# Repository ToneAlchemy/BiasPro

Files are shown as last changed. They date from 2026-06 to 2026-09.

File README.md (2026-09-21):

# 🎛️ Arduino Tube Amp BiasPro

This repository contains the complete, mathematically hardened firmware for a professional-grade, dual-probe vacuum tube BiasPro. Designed for guitar amplifier technicians, this tool provides real-time, high-resolution measurements of Plate Voltage, Cathode Current, and True Plate Dissipation (Watts & %) for power tubes (e.g., 6L6GC, EL34, 6V6, KT88).

This firmware was completely re-architected from scratch using modern, memory-safe embedded C++ principles to eliminate dynamic memory leaks and ensure rock-solid physical safety lockouts.

> **Current firmware version: v1.1.1** — see [CHANGE_LOG.md](CHANGE_LOG.md) for the full change history. Highlights since v1.0.0: a **vertically stacked, horizontally centered layout on the Tube Select and Profile Manager screens** (with improved line spacing for clear reading), a **Hold LEFT shortcut** to escape the Profile Manager directly to Tube Select, a **live plate-voltage readout on the Calibration screen** (match it to your DMM as you adjust), **sensor-glitch rejection** so a noisy ADC read can't false-release the lockout or flash 0 V, **profile-store protection** so a bad edit can't wipe your saved tube profiles, and a **flicker-free VOLTAGE LOCKOUT screen**.

| **1. Splash Screen** | **2. Tube Select** | **3. Live Bias Mode** |
| :---: | :---: | :---: |
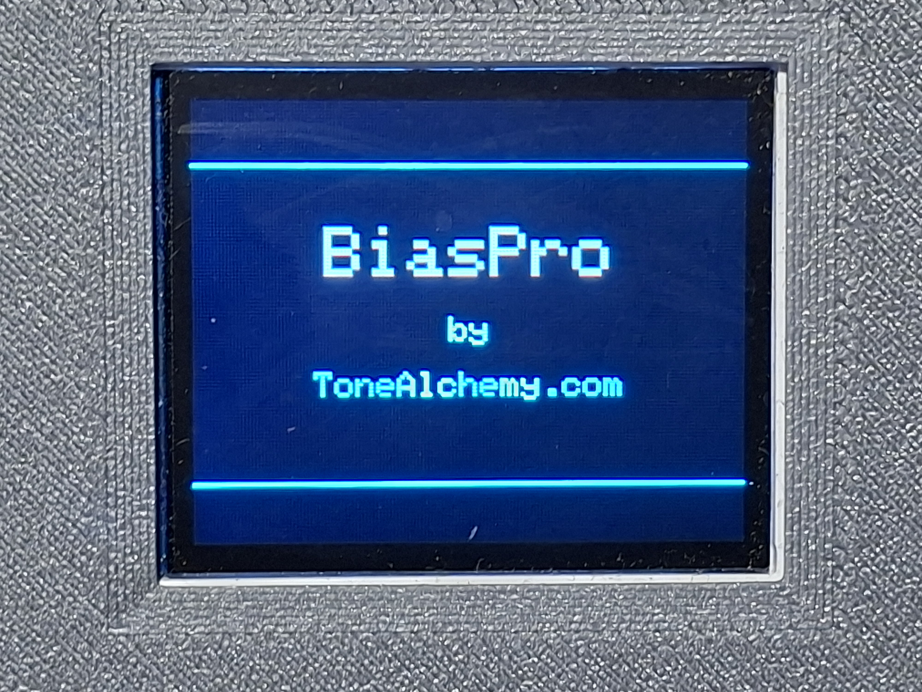
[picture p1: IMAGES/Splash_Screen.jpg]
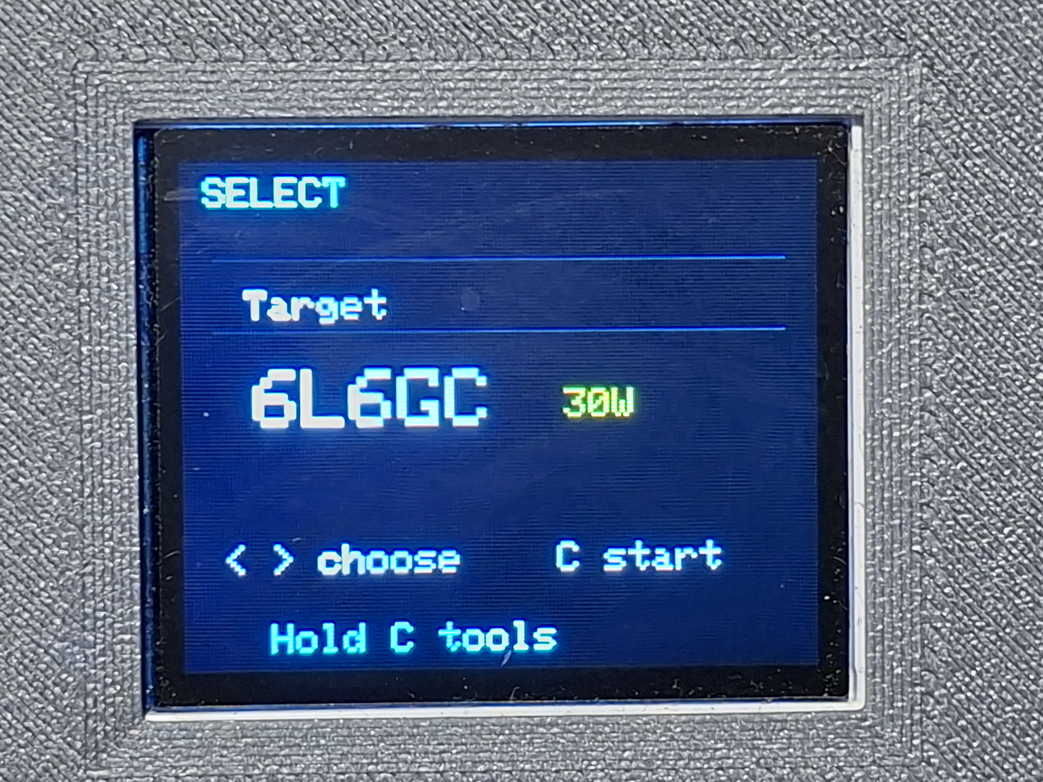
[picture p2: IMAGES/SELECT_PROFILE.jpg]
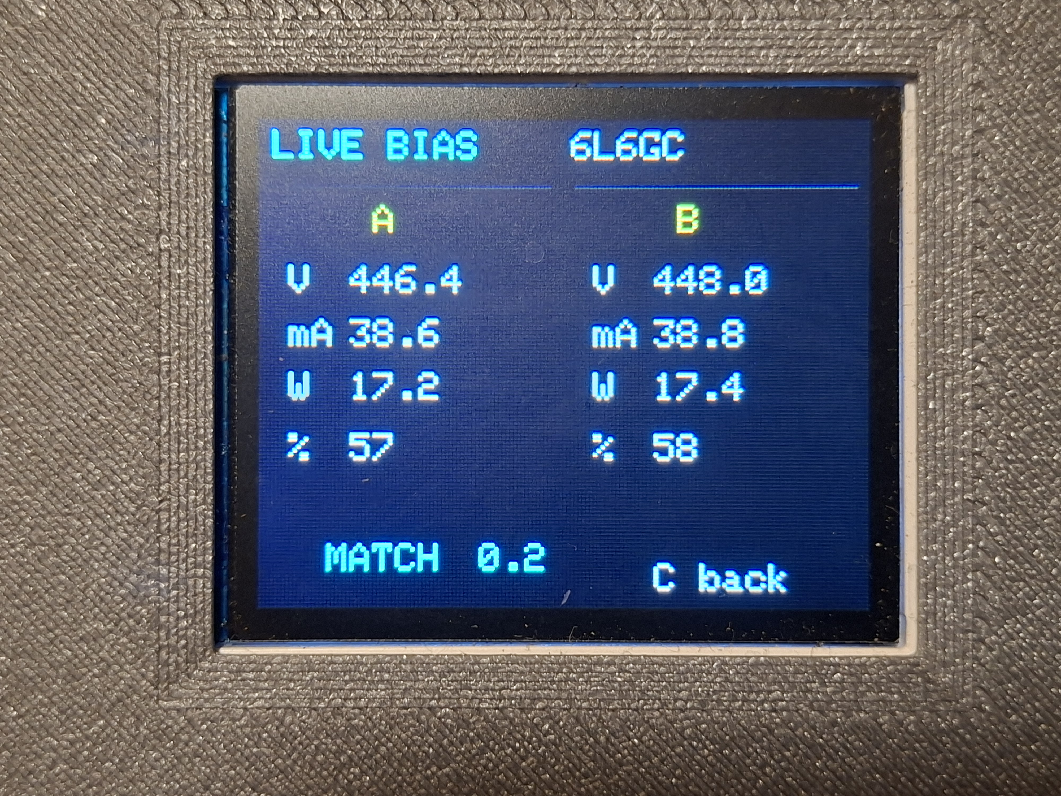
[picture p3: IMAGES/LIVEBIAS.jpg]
|  |  |  |
| **4.  Calibration** | **5. Profiles Manager** | **6. Profile Edit** |
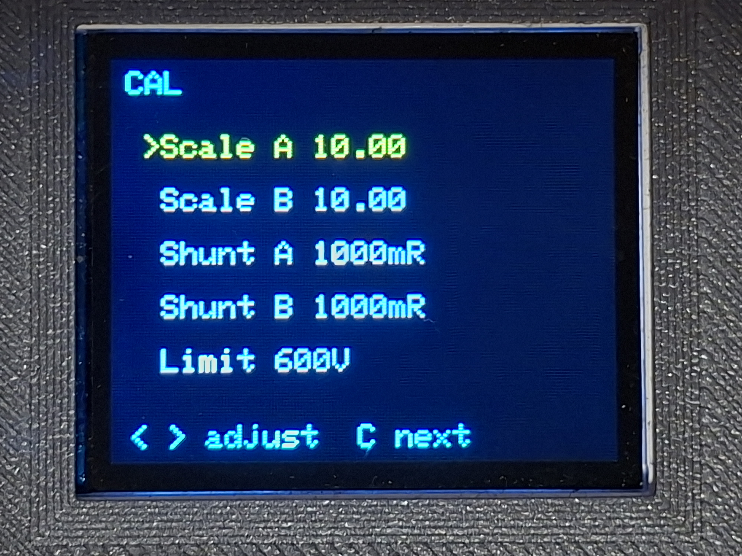
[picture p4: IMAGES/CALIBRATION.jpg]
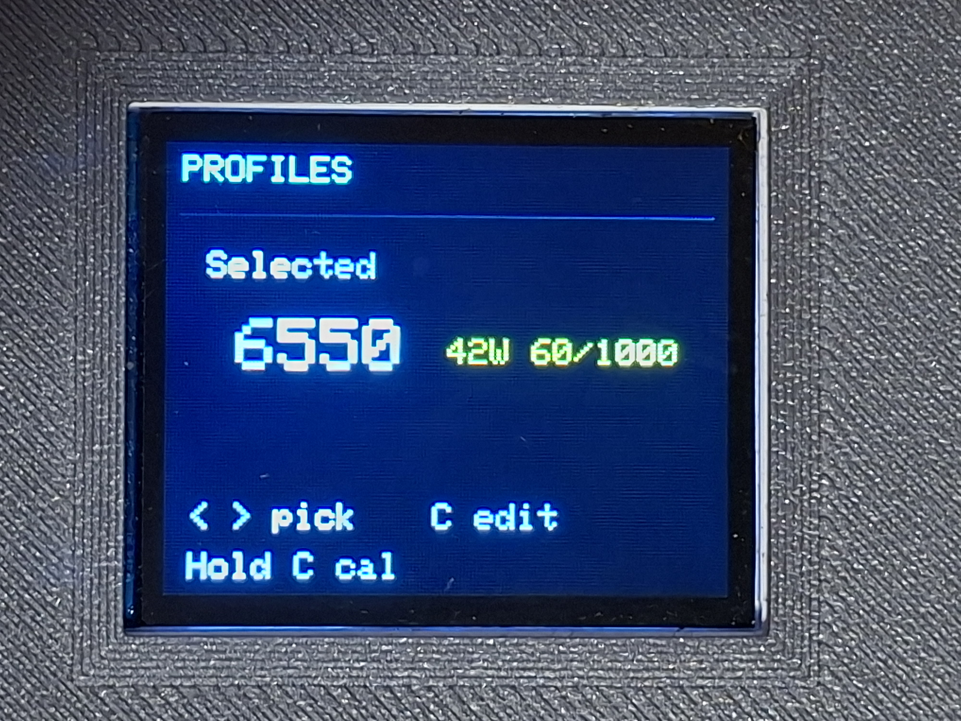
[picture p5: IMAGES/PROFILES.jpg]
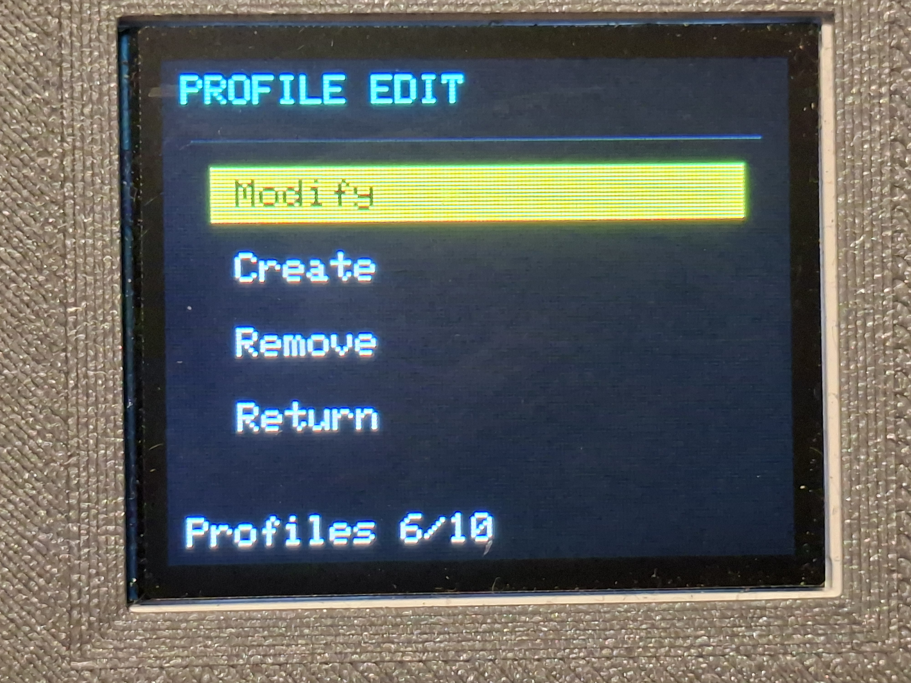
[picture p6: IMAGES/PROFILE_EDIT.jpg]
|  |  |  |
| **7. EDIT PROFILE** | **8. BiasPro Enclosure** | **9. BiasPro - Setup** |
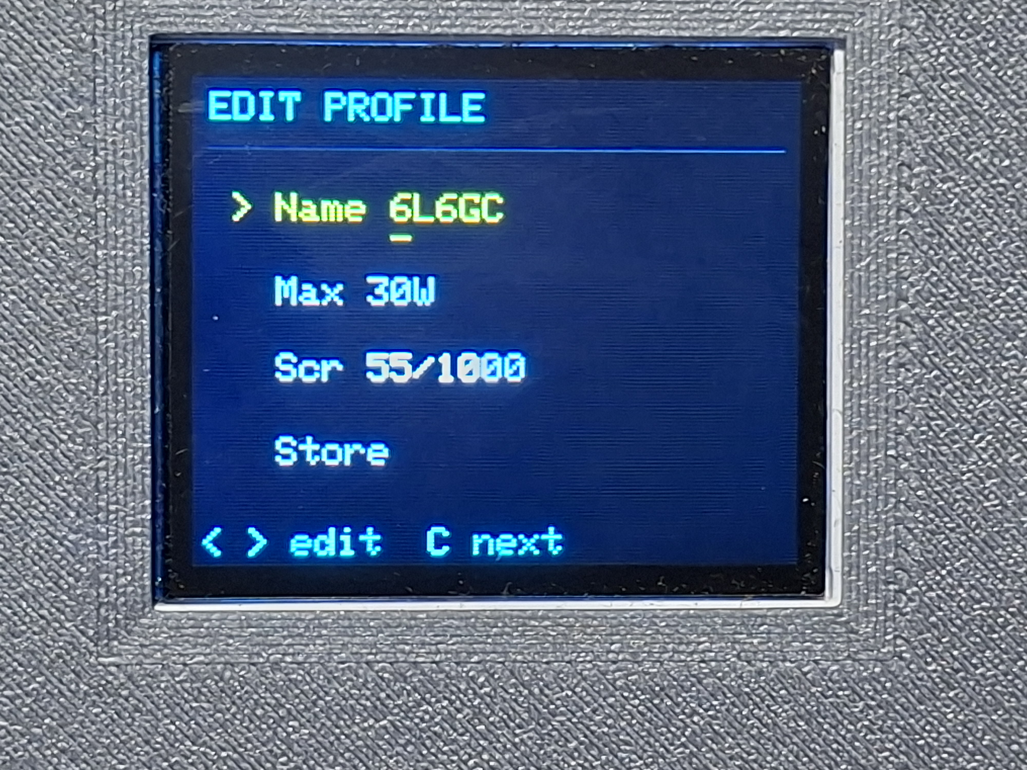
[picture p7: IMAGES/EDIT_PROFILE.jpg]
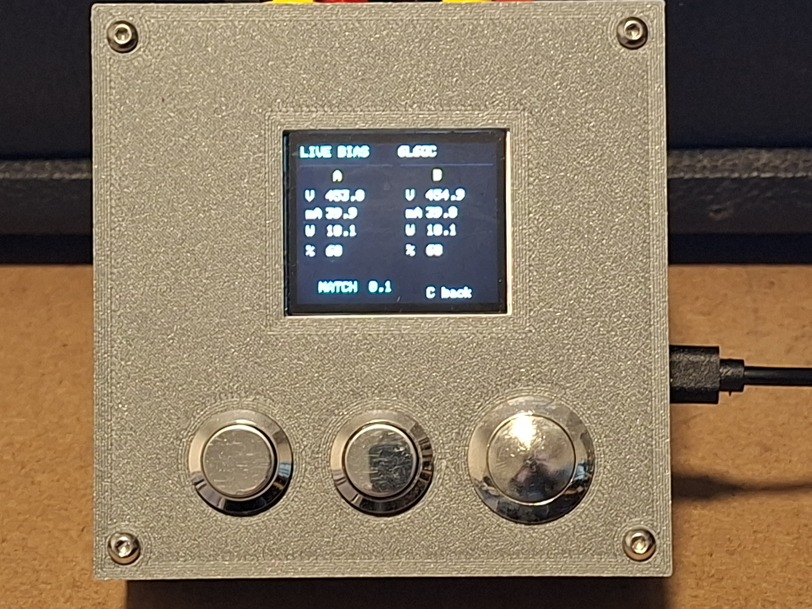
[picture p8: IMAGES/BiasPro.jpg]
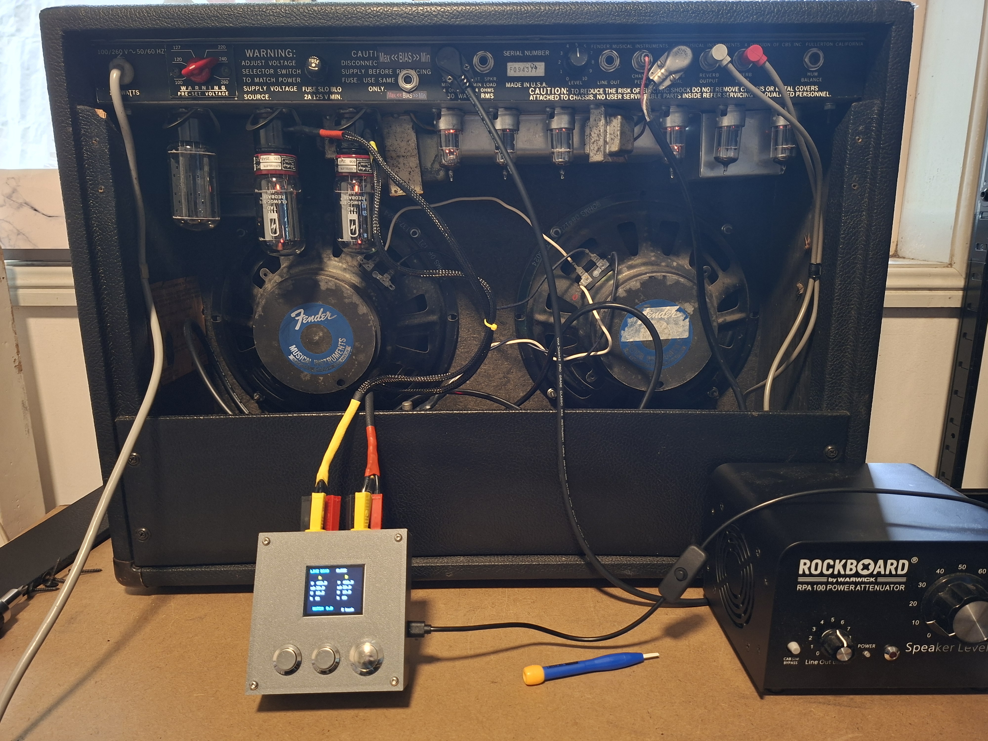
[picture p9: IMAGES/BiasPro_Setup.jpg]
|  |  |  |

---

## ⚠️ High-Voltage Safety Warning
**LETHAL VOLTAGES ARE PRESENT IN TUBE AMPLIFIERS.**

Tube amplifiers store lethal voltages in their filter capacitors even after being unplugged. This firmware is only a measurement tool; it **cannot** make unsafe wiring or handling safe. 
* Never connect the USB port to a computer while the probes are plugged into a live amplifier. 
* Always use a dummy load or speaker cabinet.
* If you are not trained in high-voltage safety, take your amplifier to a qualified technician. Build and use this project entirely at your own risk.

---

> [!CAUTION]
> ## ⚠️ WARNING: HIGH VOLTAGE SAFETY
>
> **Tube amplifiers contain lethal high voltage (often 400V–500V+), even when powered off and unplugged.**
>
> This project involves building and using test equipment that interfaces directly with these dangerous circuits.
> * **Risk of Death:** Incorrect wiring of the bias probes or misuse of this device can expose you to lethal current.
> * **Filter Capacitors:** High voltage can remain stored in the amplifier's capacitors long after the power is cut. You must know how to safely drain filter capacitors before opening any chassis.
> * **Qualified Personnel Only:** If you are not trained in high-voltage safety or are uncomfortable working with live circuits, **do not build or use this device**. Take your amplifier to a qualified technician instead.
>
> **DISCLAIMER & NO SUPPORT:** This project is provided "as is" with **no warranty and no technical support**. The author cannot provide assistance with assembly, troubleshooting, or code modifications. The author assumes no liability for injury, death, or equipment damage resulting from the use or construction of this device. **Use entirely at your own risk.**

> [!IMPORTANT]
> ### ⚡ Critical Safety: Capacitor Discharge
> Before touching any internal component or connecting probes to a chassis, you must verify the filter capacitors are drained.
>
> * **The Golden Rule:** Always measure with a multimeter to confirm 0VDC before touching anything.
> * **Discharge Tool:** Do not rely on the amp to drain itself. Use a dedicated **Capacitor Discharge Tool** to safely bleed off voltage.
>      * *DIY Tip:* You can build one using a high-wattage resistor (e.g., **2kΩ to 5kΩ, 5 Watts**) wired to a probe and an alligator clip for ground. This slows the discharge **and** prevents sparking, unlike a screwdriver short.
> * **One-Hand Rule:** When working on live amps, keep one hand in your pocket to prevent current from passing across your chest/heart.

> [!NOTE]
> ### 🛡️ Recommended Safety Gear
> If you are working inside a live amplifier chassis, we strongly recommend using the following safety equipment:
> 
> * **Isolation Transformer:** This isolates the amplifier from the mains earth ground, significantly reducing the risk of lethal shock if you accidentally touch a live component while grounded.
> * **Dim Bulb Limiter (Current Limiter):** Essential when powering up an amplifier for the first time after a repair. It prevents catastrophic damage (blown transformers) if there is a short circuit.
>      * **⚠️ CRITICAL WARNING:** Do **NOT** attempt to set the final bias while running through a Dim Bulb Limiter. The limiter drops the wall voltage, which lowers the plate voltage and gives false low bias readings. Always bypass the limiter for the final precision bias adjustment.
> * **Variac (Variable Transformer):** Highly recommended for two purposes:
>      1.  **Voltage Stabilization:** Wall voltage fluctuates. A Variac allows you to set the input voltage exactly to your country's standard (e.g., 240V in Australia, 120V in USA, 230V in UK). This ensures your bias readings are accurate and consistent, rather than drifting with high/low wall voltage.
>      2.  **Soft Start / Reforming:** Useful for slowly bringing up the voltage on vintage amplifiers to reform old capacitors safely.

> [!TIP]
> **New to Biasing?** Check out our dedicated guide:
> ### 📖 [Read the Step-by-Step Biasing Guide](BIASING_GUIDE.md)
> *Learn how to safely bias Fender Prosonic & Fixed-Bias Amps.*

---

## ⚙️ Hardware Specifications

* **MCU:** Arduino Nano / ATmega328P
* **Display:** 1.8" 128×160 ST7735/ST7735S SPI TFT (Adafruit PID 358 or compatible generic clone; see [Display Selection & Compatibility Guide](#18-tft-display-selection--compatibility-guide) below)
* **ADC:** ADS1115 (16-bit) at I2C address `0x48`
* **Inputs:** Three tactile switches (Left, Right, Center)

### Immutable Pin Map
| Function | Arduino Nano Pin |
| :--- | :--- |
| **TFT SCLK/SCL** | D13 |
| **TFT MOSI/SDA** | D11 |
| **TFT CS** | D10 |
| **TFT DC** | D9 |
| **TFT RST** | D8 |
| **Button Center** | D7 (Uses `INPUT_PULLUP`) |
| **Button Right** | D6 (Uses `INPUT_PULLUP`) |
| **Button Left** | D5 (Uses `INPUT_PULLUP`) |
| **ADS1115 SDA** | A4 |
| **ADS1115 SCL** | A5 |

### 🖥️ 1.8" TFT Display Selection & Compatibility Guide

When sourcing displays for BiasPro, you will encounter two primary hardware paths: the official Adafruit breakout or generic clone modules. Understanding their electrical architecture is essential for proper wiring and long display life:

| Feature | Adafruit 1.8" TFT Breakout (PID 358) | Generic Clone Module (`Driver IC: ST7735S` / `NOMEN_TEC`) |
| :--- | :--- | :--- |
| **Driver IC** | **ST7735R** | Usually **ST7735S** |
| **Onboard 3.3V LDO Regulator** | ✅ Yes (ultra-low-dropout 3.3V regulator) | ⚠️ **Usually present (`662K`), but verify `U1` & `J1`** |
| **Onboard Logic Level Shifter** | ✅ Yes (active CD74HC4050 buffer IC) | ❌ **None** (pins route straight to glass ribbon) |
| **5V Supply Compatibility** | ✅ Yes (accepts 3.3V – 5V on `VCC`) | ✅ Yes (if `U1` is populated and `J1` is open) |
| **5V Logic Compatibility** | ✅ Native 5V plug-and-play | ⚠️ **Requires 1kΩ to 1.5kΩ series resistors on SPI/control lines** |
| **Header Pin Labels** | `LITE, MISO, SCK, MOSI, TFT_CS, CARD_CS, D/C, RESET, VCC, Gnd` | `GND, VCC/VDD, SCL, SDA, RES/RST, DC, CS, BL/BLK` |

> [!NOTE]
> **Important Distinction on Adafruit PID 358 vs. PID 618:**  
> The official recommended reference part is the **Adafruit PID 358** assembled breakout (which includes the mounting PCB, microSD slot, 3.3V regulator, and CD74HC4050 level shifter).  
> In contrast, **Adafruit PID 618 is the raw, unmounted 1.8" TFT panel only** (flexible ribbon cable, no PCB). PID 618 is strictly 3.3V-only and requires external regulation and level shifting when paired with a 5V Arduino Nano.

---

#### Board Routing & Configuration Details

The `BiasPro_InputProtection_v3` PCB routes the global **5V** rail directly to Pin 8 (`VCC`) of the display header, and routes digital pins `D8`, `D9`, `D10`, `D11`, and `D13` straight to the display's SPI control lines without inline resistor pads. Review the configuration requirements for your specific display:

##### 1. Official Adafruit Breakout (PID 358) — *Recommended Reference Part*

The reference hardware design targets the **Adafruit PID 358** assembled breakout natively:

* **Power:** Connect `VCC` to Arduino Nano 5V (or 3.3V; the onboard regulator safely handles 3.3V–5V input) and `GND` to Arduino GND.
* **Signals:** Wire directly to the Arduino Nano with **no external resistors required** (the onboard CD74HC4050 buffer translates 5V logic down to 3.3V safely):
  * Nano `D13` → Adafruit `SCK`
  * Nano `D11` → Adafruit `MOSI`
  * Nano `D10` → Adafruit `TFT_CS`
  * Nano `D9`  → Adafruit `D/C`
  * Nano `D8`  → Adafruit `RESET`
* **Backlight:** Connect `LITE` to 3V3 or 5V (or to an Arduino PWM pin if software brightness control is desired).
* **Unused Pins:** `CARD_CS` and `MISO` belong to the onboard microSD card socket and remain unconnected in BiasPro.
* **Firmware Support:** BiasPro’s firmware uses `tft.initR(INITR_18BLACKTAB)` via the `Adafruit_ST7735` library, targeting the PID 358 natively.

---

##### 2. Generic / Chinese Clone Modules (ST7735S)

Budget 8-pin breakout modules (frequently marked *Driver IC: ST7735S* or *NOMEN_TEC V2.0*) run on native 3.3V silicon and lack active logic-level translation buffers.

* **VCC Power Compatibility (`U1` & `J1` Check):**
  * Inspect the rear PCB of the module: most clones include a 3-pin 3.3V LDO regulator marked **`662K`** (or `AMS1117-3.3`) at footprint **`U1`**, alongside an unbridged solder jumper **`J1`**.
  * If `U1` is populated and `J1` is open, feeding 5V into `VCC` is completely safe (the regulator steps 5V down to 3.3V for internal panel power).
  * **Warning:** If `U1` is unpopulated and `J1` is bridged, the module is strictly 3.3V-only. Connecting 5V to `VCC` will destroy the panel.
* **5V Logic Levels & Clamping:**
  * Because generic modules omit active buffer ICs, driving them directly with the Nano's 5V SPI lines forces the ST7735's internal silicon clamping diodes to shunt the excess voltage down to 3.3V.
  * **Intermittent Bench Biasing (Stock Direct Connection):** For standard tube biasing workflows (5 to 15 minutes of bench runtime per amplifier), the direct connection operates reliably without immediate failure.
* **Extended / Continuous Duty Cycles (Recommended Protection):** For long-term reliability and day-long bench operation, insert **1kΩ to 1.5kΩ series resistors** into every digital control line to eliminate clamping stress and keep the display controller cool:
  * Nano `D13` → [1kΩ Resistor] → Display `SCL` / `SCK`
  * Nano `D11` → [1kΩ Resistor] → Display `SDA` / `MOSI`
  * Nano `D10` → [1kΩ Resistor] → Display `CS`
  * Nano `D9`  → [1kΩ Resistor] → Display `DC` / `A0`
  * Nano `D8`  → [1kΩ Resistor] → Display `RES` / `RESET`
* **PCB Assembly Note:** Because the `BiasPro_InputProtection_v3` PCB routes the Nano directly to the display header without inline resistor pads, builders opting for series resistors should wire the clone module off-board or install inline resistors along the wiring harness rather than soldering the display directly flush into the PCB header.
* **Backlight (`BL` / `BLK`):** The onboard transistor (`Q1` / `J3Y`) and base resistor handle switching. Connect `BL` to the Nano's `3V3` pin, or to an Arduino GPIO pin through a 1kΩ resistor if software dimming is desired.

---

## 🛠️ Build & Flash Instructions

### 1. Pinned Dependencies
To guarantee a successful compile, you **must** use these exact library versions in the Arduino IDE:
* `Adafruit GFX Library` v1.12.5
* `Adafruit ST7735 and ST7789 Library` v1.11.0
* `Adafruit BusIO` v1.17.4

### 2. CRITICAL: 99% Flash Memory Limit & Bootloaders
The firmware compiles to approximately **30,626 bytes** of program storage. This is a very tight fit on older hardware, but it will successfully flash to both new and old Arduino Nanos.

* **Newer Arduino Nano (Standard Bootloader):** If you have a newer official Nano or a high-quality modern clone, use the `Processor: ATmega328P` setting in the Arduino IDE. These boards use the modern *Optiboot* bootloader, which leaves 32,256 bytes of usable flash space. The firmware will fit easily with roughly **1.6KB to spare**.

* **Older Arduino Nano & Generic Clones (Old Bootloader):** Many cheaper clones and older Nanos use the legacy bootloader, which takes up more space and leaves exactly 30,720 bytes of usable flash space. The firmware **will still successfully flash** using the `Processor: ATmega328P (Old Bootloader)` setting, fitting with roughly **94 bytes to spare**:
  ```text
  Sketch uses 30626 bytes (99%) of program storage space. Maximum is 30720 bytes.
  Global variables use 750 bytes (36%) of dynamic memory, leaving 1298 bytes for local variables. Maximum is 2048 bytes.
  ```
  It works perfectly, but you have very little room to add additional features or text without overflowing the memory.

* **Need more space on an old Nano?** You can manually upgrade an old Nano to the modern *Optiboot* bootloader using an ISP programmer. Once upgraded, you simply change your board selection in the Arduino IDE to **"Arduino Uno"** to unlock the extra 1.5KB of flash space.

### 3. EMI & I2C Freeze Protection
Tube amplifiers are electrically noisy environments. High voltage spikes, flyback EMF, or loose tube socket connections can create strong Electromagnetic Interference (EMI) that can lock up the internal I2C bus connecting the Arduino to the ADS1115 ADC.

To protect against these EMP-like events, this firmware completely bypasses the standard Adafruit ADC library and manually writes to the I2C registers. More importantly, it utilizes the modern `Wire.setWireTimeout(25000, true)` feature. 

* **How it works:** If the I2C bus freezes due to interference, the system detects the hang within 25 milliseconds, automatically resets the I2C hardware pins, and immediately resumes reading the Bias probes without ever rebooting the Arduino or losing your place on the screen.

* **Why no Hardware Watchdog Timer (WDT)?** Older versions of this project used the hardware WDT. However, a severe silicon bug in common LGT8F328P Arduino Nano clones caused the WDT to trigger infinite boot-loop crashes during UI updates. The software-level `Wire` timeout is infinitely more reliable, handles EMI elegantly, and completely avoids these bootloader bugs.

#### Hardware I²C Pull-Up Reinforcement (EMI Hardening)
In addition to the software timeout recovery, the physical BiasPro hardware reinforces the ADS1115 I²C bus with auxiliary pull-up resistors:
* **`SDA` $\rightarrow$ 4.7kΩ $\rightarrow$ `VDD`**
* **`SCL` $\rightarrow$ 4.7kΩ $\rightarrow$ `VDD`**

These $4.7\text{ k}\Omega$ metal-film resistors were added during live amplifier testing to strengthen the I²C bus against EMI-induced corruption and bus lockups in electrically aggressive valve-amplifier environments. By lowering the bus impedance and sharpening the $SDA$/$SCL$ rising edges, the bus becomes significantly more immune to capacitively coupled noise from high-voltage plate leads and transformer fields.

Many common ADS1115 breakout modules already include $10\text{ k}\Omega$ onboard pull-up resistors. Adding external $4.7\text{ k}\Omega$ resistors places them in parallel, resulting in an effective bus pull-up impedance of approximately $\approx 3.2\text{ k}\Omega$ (drawing only $\approx 1.56\text{ mA}$ sink current at 5V, comfortably within the $3\text{ mA}$ I²C standard limit). These hardware pull-ups work synergistically with the firmware’s `Wire.setWireTimeout` mechanism to deliver rock-solid stability.

---

## ⚠️ Troubleshooting

### 1. Upload Failed? (stk500 Error)
If you are unable to upload the firmware and see an error like `stk500_recv(): programmer is not responding`:

* **The Cause:** You are likely using an older Arduino Nano (or a generic clone) that uses the legacy bootloader.

* **The Fix:** In the Arduino IDE, go to **Tools > Processor** and change the setting from "ATmega328P" to **"ATmega328P (Old Bootloader)"**. Then try uploading again.
* *Note:* Newer official Nanos (and USB-C versions) usually use the standard "ATmega328P" setting.

### 2. The "Boot Loop" Issue (Legacy Hardware)
Some older Arduino Nano boards (and many low-cost clones) came with an outdated "Bootloader" that had a bug preventing the chip from recovering correctly after a hardware Watchdog Reset. 

* **The Fix:** This has been permanently fixed in this modern codebase! We completely stripped out the hardware Watchdog Timer and replaced it with a targeted `Wire.setWireTimeout` bus reset. You should no longer experience infinite boot loops when encountering EMI. If you do, ensure you have correctly installed the `Wire` library updates in the Arduino IDE.

### 3. Adafruit Display Clones ST7735 1.8" TFT - White Screen / Static / Wrong Colors?
If your display lights up but shows static, garbage pixels, or wrong colors:

* **The Cause:** You likely have a "Green Tab" or "Red Tab" clone display. The plastic tab on the screen protector often indicates the internal driver version.

* **The Fix:** Open the firmware source code (`DisplayManager.cpp` or main `.ino` configuration) and find the initialization line: `tft.initR(INITR_18BLACKTAB);` 
Change it to one of the following and re-upload until the screen looks correct:
  * `tft.initR(INITR_18GREENTAB);`
  * `tft.initR(INITR_18REDTAB);`

### 4. Arduino Nano "L" LED Flickering Constantly?
If you notice the onboard yellow/orange **`L`** LED on your Arduino Nano flickering continuously while the device is running:

* **This is completely normal and indicates healthy operation.**
* On the Arduino Nano hardware, the onboard `L` LED is hardwired directly to digital pin **`D13`**.
* In BiasPro, `D13` serves as the high-speed SPI Clock (`TftSclkPin`). Every time the live bias values update (multiple times per second), thousands of SPI clock pulses toggle D13 at high frequency.
* The flickering `L` LED effectively functions as a live hardware activity monitor showing active SPI communication between the ATmega328P and the display.

---

## 💻 Software & Development Environment

This project is written as a standard Arduino sketch (`.ino`) and was developed using the official **Arduino IDE**.

* **Recommended Method:** We strongly recommend using the **Arduino IDE** for the easiest setup. Its built-in *Library Manager* (Tools > Manage Libraries) makes it simple to install the required dependencies (e.g., Adafruit GFX) without complex manual configuration.

* **Alternative IDEs:** Advanced users can compile this code in other environments, such as **Visual Studio Code (with PlatformIO)** or **Microchip Studio**. However, please note that you will need to manually manage library paths and dependencies.
* **📥 Download Official Arduino IDE:** [Download Official Arduino IDE](https://www.arduino.cc/en/software)

---

## 🧪 Tests

The pure calculation and storage logic (bias math, probe classification, EEPROM
checksums/validation, and the over-voltage protection state machine) lives in
Arduino-independent units (`MathCalculations`, `ProtectionSystem`, `StorageCore`)
so it can be verified on a PC with any C++17 compiler — no board required. The
host tests link the **actual firmware sources**, not a copy, so they cannot drift
from what ships.

```bash
# From the repository root, with g++ (or clang++):
g++ -std=c++17 -I BiasPro test/host_calculation_tests.cpp \
    BiasPro/MathCalculations.cpp BiasPro/ProtectionSystem.cpp \
    BiasPro/StorageCore.cpp -o biaspro_host_tests
./biaspro_host_tests        # expect: "host calculation tests passed"
```

A second, source-level UI regression check (PowerShell) asserts that the display
code keeps using its incremental-redraw pattern and that the safety-screen
routing stays intact:

```powershell
powershell -ExecutionPolicy Bypass -File test/screen_redraw_static_check.ps1
```

---

## Features

BiasPro introduces professional-grade data integrity and safety features not found in standard DIY alternatives.

### 🛠 Core Functionality
* **Dual Probe Measurement:** Simultaneous real-time monitoring of Tube A and Tube B.

* **True Plate Dissipation:** Calculates power (Watts) and dissipation percentage based on the specific tube type.

* **Screen Current Correction:** Implements industry-standard math to subtract estimated screen current, ensuring the displayed bias represents true *Plate* dissipation, not just Cathode current.

### 💾 Robust Data Integrity
* **Checksum Protection:** The EEPROM data includes a computed checksum. If the memory is corrupted or a new chip is installed, the system detects the error and automatically restores safe default values, preventing dangerous behavior.

* **Safety Clamps:** The Calibration Menu now prevents users from accidentally setting dangerous values (e.g., setting a shunt resistor to 0.0Ω or a voltage scaler to 0), effectively "clamping" entries to safe, realistic ranges.

* **Profile Store Protection:** Your custom tube profiles are validated on both save and load. A malformed entry (for example a blank name) is rejected rather than written, so a bad edit can never silently wipe your saved profiles back to defaults on the next power-up.

### 🛡️ Safety & Reliability
* **Active Over-Voltage Monitor:** While in **Live Bias mode**, the plate voltage is checked on every measurement cycle; if it exceeds the configured limit the interface locks and displays a red "LOCKOUT" warning until the voltage falls back into the safe band. (The lock, once tripped, persists across screens until released.) **This automatic check runs only in Live Bias mode — it is _not_ active on the Calibration screen**, even though that screen shows a live voltage. During calibration, rely on your DMM and your own judgement (see the Calibration Guide warning below).

* **Safety Hysteresis:** The system requires a voltage drop of 50V (hysteresis) before resetting the safety lock, preventing rapid toggling near the limit.

* **Input Debouncing:** Advanced state-machine logic eliminates switch "recoil" and bounce, ensuring the cursor never jumps unintentionally.

* **Sensor-Glitch Rejection:** A failed or corrupted ADC read (for example from an EMI burst) is flagged invalid rather than trusted. An invalid reading can **never** release an active voltage lockout, and Live Bias mode holds the last good measurement instead of momentarily flashing 0 V.

* **Flicker-Free Display:** Every screen — including the red VOLTAGE LOCKOUT alert — uses incremental redraw, so critical readouts stay rock-steady instead of strobing.

* **Centered, Stacked UI Layout:** Selection screens (Tube Select and Profile Manager) feature vertically stacked, horizontally centered text elements with balanced line spacing for improved readability.

### ⚙️ On-Board Calibration
* **Software Calibration:** Shunt resistance and Voltage Divider scaling can be adjusted via the screen menu and saved to EEPROM. You do not need to edit the source code to calibrate the unit. Edits save **automatically** when you advance to the next field or leave the screen — there is no separate "save" step — which also minimises wear on the EEPROM.

* **Live Voltage Feedback:** While adjusting the Scale or Shunt fields in Calibration mode, the screen displays a live, non-blocking computed plate voltage (refreshed every ~350 ms) for the active probe. This allows you to match the calibration to your DMM readings in real time.

---

## 🧠 How It Works (Theory of Operation)

For those interested in the engineering, here is how the BiasPro safely measures high-voltage tube amplifiers.

### 1. Measuring Plate Voltage (The Voltage Divider)
The Arduino cannot measure 500V directly, and the ADS1115 is configured with a high-resolution Programmable Gain Amplifier (PGA) range of ±0.256V (256 mV) to maximize measurement accuracy.
* **The Circuit:** Inside the probe, a **Voltage Divider** network (1MΩ high-side, 100Ω low-side) scales the high voltage down to a safe millivolt range (0-256 mV).
* **The Math:** The device measures this low millivolt reading and multiplies it by the **Voltage Scale Factor** (defaults to 10.00, calibrated in software) to calculate the true High Voltage.
    * *Example:* 450V from the amp is stepped down by the 10,001:1 divider to approximately 45mV (0.045V) at the ADC input. The firmware multiplies this 45mV reading by the Scale Factor (10.00) to display "450V" on the screen.

### 2. Measuring Bias Current (The Shunt Resistor)
To measure current, we use **Ohm's Law** (`V = I × R`).
* **The Circuit:** The tube's cathode current flows through a precision **1Ω Shunt Resistor** to ground.

* **The Measurement:** The current flowing through the resistor creates a tiny voltage drop across it (e.g., 35mA of current creates 35mV).

* **The ADC:** The high-precision **ADS1115 ADC** measures this tiny voltage drop with extreme accuracy. The Arduino then converts that millivolt reading directly into milliamps (since 1mV = 1mA across a 1Ω resistor).

### 3. Calculating Dissipation (The Wattage)
Once the system knows the Voltage (V) and the Current (I), it calculates the Plate Dissipation in real-time.

* **Formula:** `Watts = Plate Voltage × Plate Current`

* **Screen Correction:** If enabled, the system first subtracts the estimated Screen Current from the total current to ensure the Wattage displayed is for the **Plate only**, providing the most accurate bias reading possible.

---

## Bill of Materials (BOM)

| Quantity | Component | Description |
| :--- | :--- | :--- |
| 1 | Arduino Nano (Recommended: USB-C Version) | Microcontroller board (ATmega328P) |
| 1 | Adafruit ST7735 1.8" TFT | 160x128 Color TFT Display (SPI) |
| 1 | ADS1115 16-Bit ADC Module | High-precision 4-channel ADC (I2C) |
| 3 | Tactile Push Buttons | Menu navigation (Left, Right, Center/Select) |
| 1 | Project Enclosure | 3D printed case (See below) |
| - | Hook-up Wire | 22 AWG for internals |
| 2 | Bias Probes | Octal (8-pin) probes (e.g., TubeDepot Bias Scout or DIY) |

* **Download Link:** [Bill of Materials (BOM) for the BiasPro.txt](./HARDWARE%20-%20PCB%20KICAD/Bill%20of%20Materials%20(BOM)%20for%20the%20BiasPro.txt)

---

## 🛑 Hardware Compatibility & Critical Warnings

Before sourcing parts, please review these critical hardware constraints to ensure your build works correctly.

### 1. ADC Module: ADS1115 Only (No ADS1015)

* **⚠️ CRITICAL:** You **MUST** use the **ADS1115 (16-Bit)** ADC module.

* **Do NOT use the ADS1015:** This is a cheaper, 12-bit version that looks identical.

* **The Issue:** The firmware uses a specific multiplier (`0.0078125 mV/bit`) calculated for 16-bit resolution. If you use an ADS1015, your bias readings will be incorrect by a factor of 16.

### 2. Display: ST7735 TFT Only (No OLEDs)

* **Required:** Adafruit **ST7735 1.8" Color TFT** (or compatible).

* **Not Supported:** This firmware is **NOT** compatible with monochrome OLED displays (SSD1306 or SH1106) used in other versions.

### 3. Arduino Nano Bootloader

* **Recommendation:** We recommend buying an Arduino Nano with the modern **Optiboot** bootloader (often found on USB-C versions) as it provides more flash memory and overall better stability.

### 4. Power Source (No Heater Power)
* **Supported:** Isolated USB Wall Charger or 9V Battery.

* **Not Supported:** Do **NOT** attempt to power this unit directly from the amplifier's 6.3V AC heater lines.

* **The Risk:** This hardware revision does not include the necessary rectification circuitry. Connecting heater lines to the Arduino will destroy the unit.

### 5. Isolation Transformers & USB

* **Clarification:** Even if you plug the amplifier into an **Isolation Transformer**, it is **STILL UNSAFE** to connect the BiasPro's USB port to a computer while probing.

* **The Physics:** Most isolation transformers pass the **Earth Ground** pin straight through. This means the Ground Loop danger persists. **Never connect USB to a PC while the probes are in an amp. If you do so, you do it at your own risk!**

### 🛠️ Building the Probes (Recommended Kit)

We highly recommend the **Tube Depot Bias Scout Kit** for your hardware. It provides a professional, safe, and robust enclosure for the socket and resistor.

* **Product Link:** [Tube Depot Bias Scout Kit](https://www.tubedepot.com/products/tubedepot-bias-scout-kit)

* **Assembly Manual:** [Download PDF Instructions](https://s3.amazonaws.com/tubedepot-com-production/spree/attached_files/td_bias_scout_assy_manual_v3.2.pdf)

**Assembly Notes for this Project:**

1. **The Resistor:** The kit includes a **1Ω 1W resistor**. This is perfect for this project and matches the default calibration (1.00Ω).

2. **Wiring Colors:** If you follow the standard instructions, the output plugs will match this project's wiring guide:
   - **Red:** Plate Voltage (Connect to PCB `V_IN` via voltage divider).
   - **Black:** Ground (Connect to PCB `GND`).
   - **White:** Cathode Current (Connect to PCB `ADC_IN`).

3. **Connection:** You can either cut the banana plugs off and wire them directly to your PCB/Enclosure, or install female banana jacks on your BiasPro enclosure for a detachable probe.

---

## 🔌 DIY Probe Construction & Theory
While we recommend the **Tube Depot Bias Scout Kit** for the easiest assembly, you can build your own probes using the Bias Scout Kit Instructions with standard components.

### 🛠️ DIY Parts List (Per Probe)
To build one probe, you will need:
* **1x Octal Tube Base:** (e.g., P-SP8-47X) - The male plug that goes into the amp.
* **1x Octal PCB Socket:** (e.g., P-ST8-810-PCL) - The female socket the tube plugs into.
* **1x 1Ω Resistor:** (2 Watt or greater, 1% Tolerance) - *Current Shunt*.
* **1x 1MΩ Resistor:** (1/2 Watt or greater, 1% Tolerance) - *Voltage Divider High Side*.
* **1x 100Ω Resistor:** (1/8 Watt or greater, 1% Tolerance) - *Voltage Divider Low Side*.
* **3-Conductor Cabling:** Shielded audio cable or twisted wire.
* **Banana Plugs / Jacks:** To connect to the main unit.
* **Assembly Manual:** [Download PDF Instructions](https://s3.amazonaws.com/tubedepot-com-production/spree/attached_files/td_bias_scout_assy_manual_v3.2.pdf)
  
> [!NOTE]
> The **Hoffman Amps Bias Checker** probe design will **NOT** work with this project. That probe only measures Cathode Current. This project requires probes that measure both Plate Voltage *and* Cathode Current.

---

## 3D Printed Enclosure

A custom enclosure has been designed to house the Arduino Nano, Display, and Buttons safely.

* **Design Platform:** TinkerCAD

* **Editable Source:** [BiasPro Enclosure V11 Files](https://www.tinkercad.com/things/gKRXVebJSTF/edit?sharecode=gUTg7qwfboPwH2RXnympp6uQYQx4FWwdrr1dFZcTKMg) *(Note: You must be logged into Tinkercad to access this link)*

* **Ready-to-Print Files:** [BiasPro_Enclosure_STL](./HARDWARE%20-%20PCB%20KICAD/BiasPro_Enclosure_STL)
  
**Printing Notes:**

You can export the `.STL` files directly from the link above. Standard PLA or PETG is suitable for this project. The case is designed to keep the low-voltage electronics isolated and secure.

---

## PCB Design & Fabrication

For a cleaner build and enhanced reliability, a custom PCB has been designed to replace hand-wiring. This board hosts the Arduino Nano, ADS1115, and input connectors.

### Key Hardware Features

* **Hardware Input Protection:** The board includes **1N4733A Zener Diodes (5.1V)** on the probe inputs. These clamp any incoming voltage spikes to ~5.1V, protecting the sensitive ADS1115 ADC from damage in case of a tube failure or surge.

* **Simplified Assembly:** Eliminates the "rat's nest" of wires common in DIY builds.

* **Fabrication Ready:** You can use the provided Gerber/KiCad files to order these boards from any fabrication house (e.g., PCBWay, JLCPCB, OSH Park).

### PCB Board Views
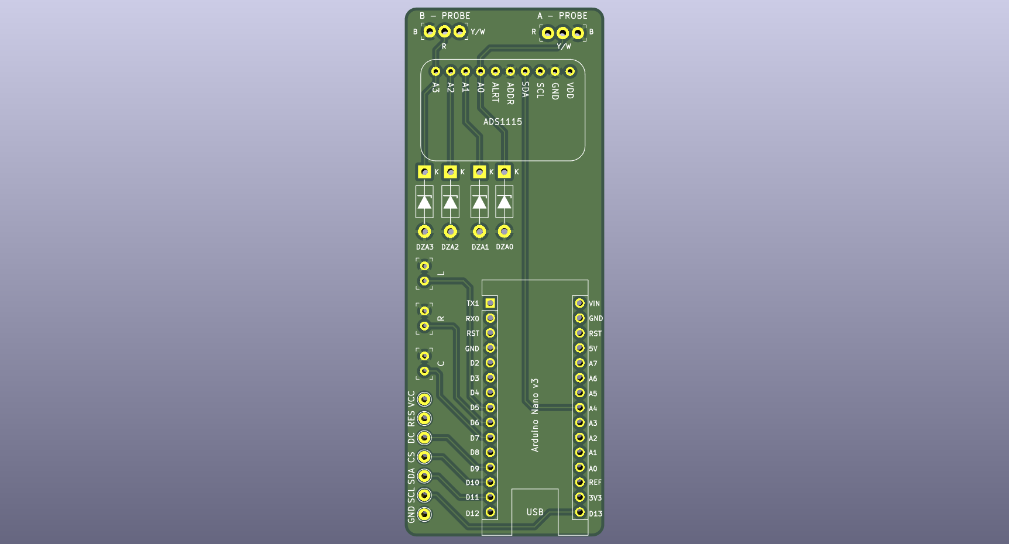
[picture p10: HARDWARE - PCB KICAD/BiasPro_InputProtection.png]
PCB Board Layout


### PCB Board Components Views
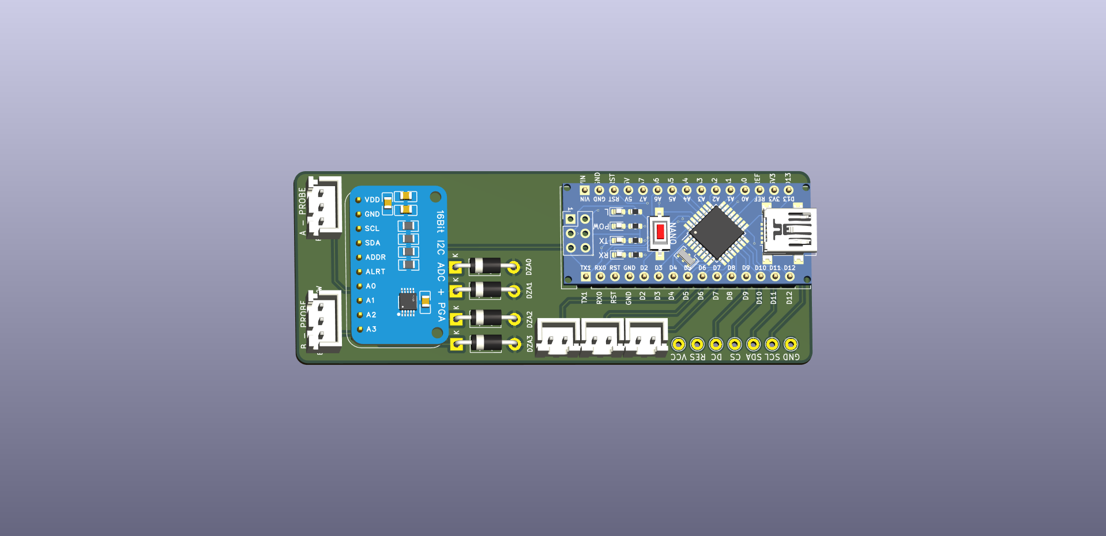
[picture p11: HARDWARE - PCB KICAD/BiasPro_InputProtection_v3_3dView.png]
PCB Board Layout - Components


### Schematic layout
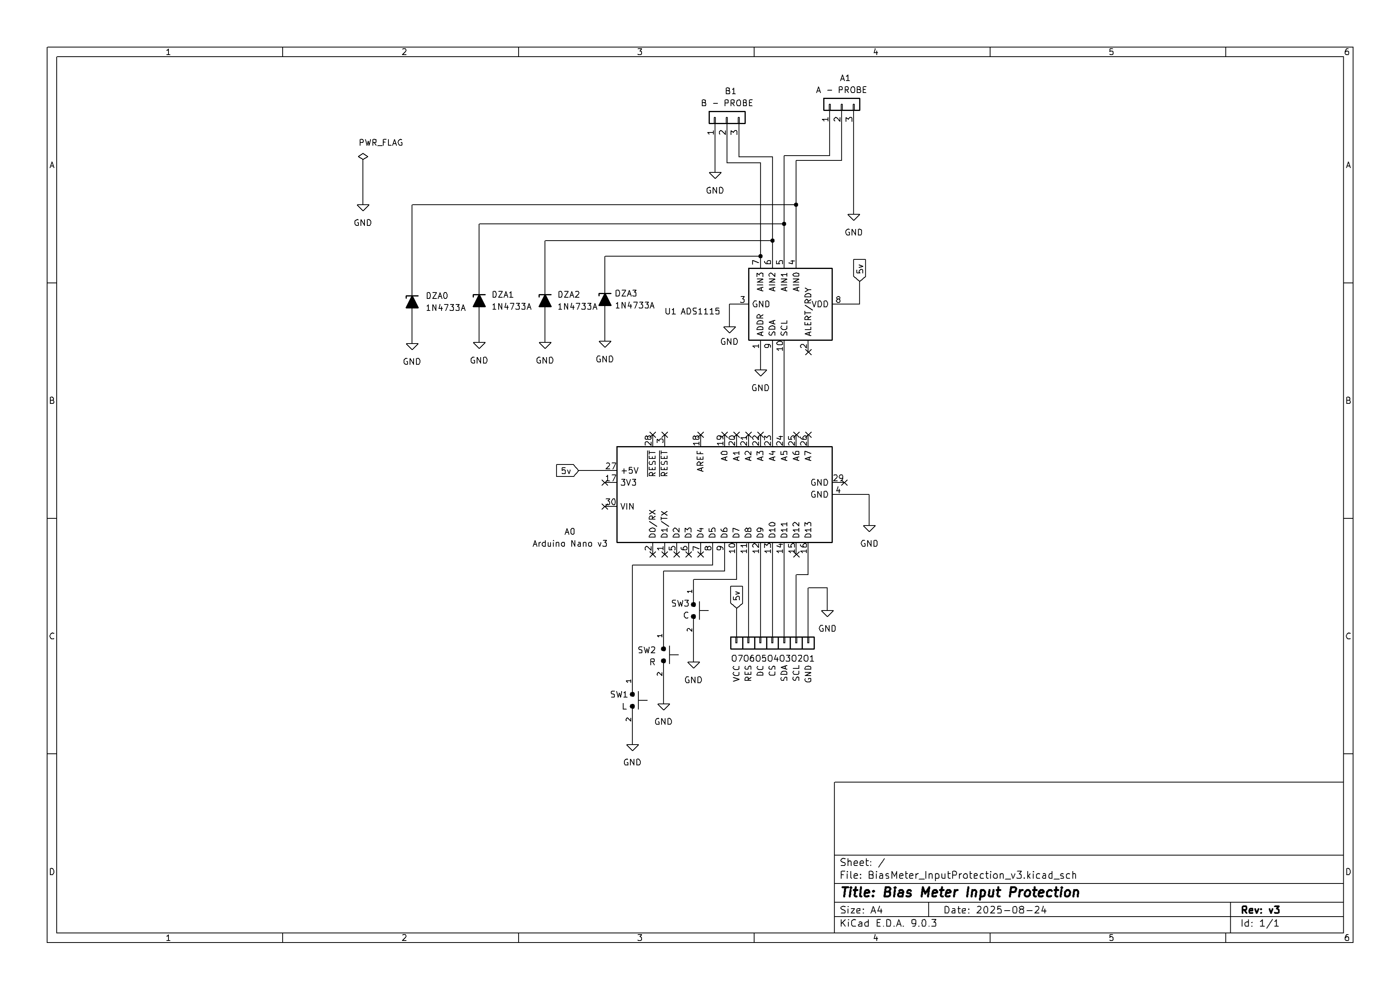
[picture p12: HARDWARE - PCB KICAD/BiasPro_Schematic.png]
PCB Schematic


* **Download Link:** [BiasPro - KICAD](./HARDWARE%20-%20PCB%20KICAD/BiasPro%20-%20KICAD)
  
**📥 Get KiCad Software:** [Download Official KiCad](https://www.kicad.org)

---

## Wiring / Pinout Guide

### Arduino Nano Connections
| Component | Pin Name | Nano Pin |
| :--- | :--- | :--- |
| **Buttons** | Left Button | D5 |
| | Right Button | D6 |
| | Select/Center | D7 |
| **Display (ST7735)** | CS | D10 |
| | DC (A0) | D9 |
| | RST | D8 |
| | SDA (MOSI) | D11 |
| | SCK (SCLK) | D13 |
| **ADC (ADS1115)** | SDA | A4 |
| | SCL | A5 |
| | VCC | 5V |
| | GND | GND |

### Arduino Nano Pinout 

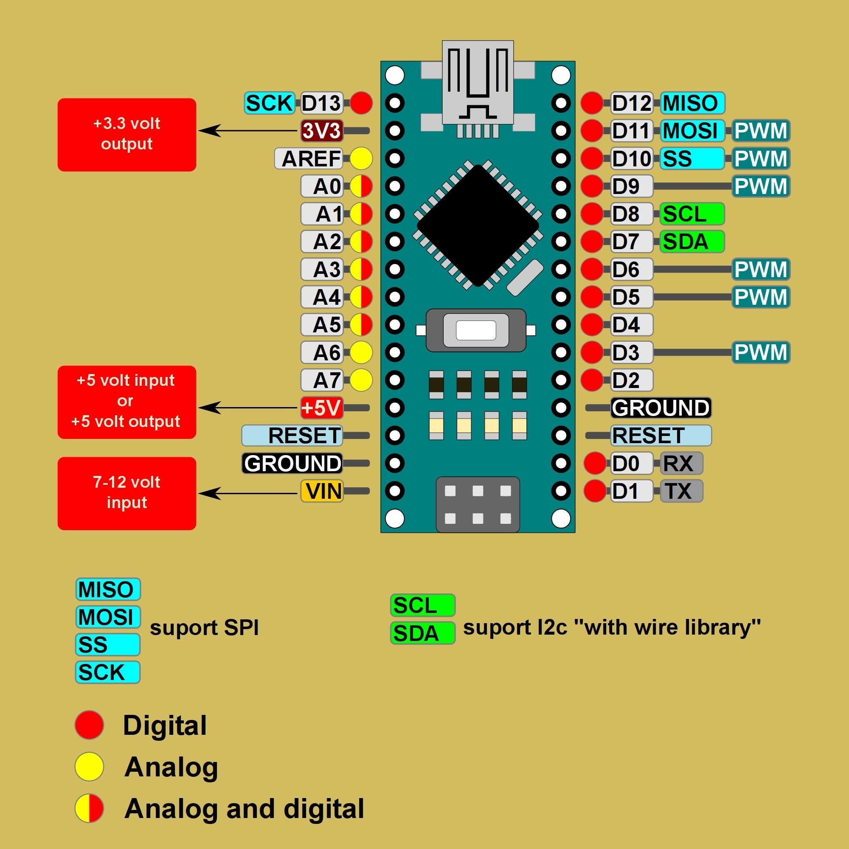
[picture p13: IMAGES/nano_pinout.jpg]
Arduino Nano Pinout


### 🔌 Probe Wiring (Octal Sockets)

If you are building your own probes, correct wiring is essential for the math to work.
* **Pin 3 (Plate):** Connects to the Voltage Divider.
* **Pin 8 (Cathode):** Connects to the Shunt Resistor (and Ground).
* **Pin 1 & 8:** Often tied together in 6L6/EL34 amps.

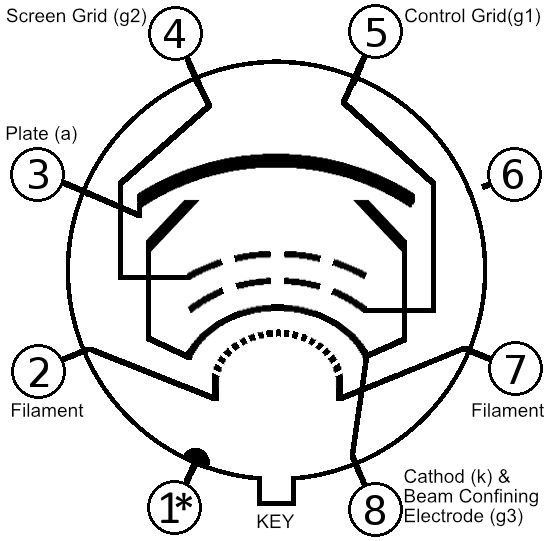
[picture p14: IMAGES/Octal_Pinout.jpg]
Standard Octal 8-Pin Pinout Bottom View


*Figure: Standard Octal (8-Pin) Pinout (Bottom View).* 

---

## Powering the Device (Crucial Safety Info)

Correctly powering the Arduino Nano is critical to prevent damage to your computer, the BiasPro, or the amplifier.

### 1. Recommended: Separate USB Power Adapter

The safest way to power this device during use is with a dedicated USB wall charger (like a standard phone charger).
* **Specs:** 5V Output, at least 500mA (0.5A).

* **Connector:** Mini-USB or USB-C (for Nano).

* **⚠️ IMPORTANT - 2-Prong Only:** You must use a charger that has only **2 prongs** (ungrounded).
    * **Why?** Tube amplifiers are grounded to Earth. If you use a grounded (3-prong) power adapter for the Arduino, you may create a **Ground Loop**. This can introduce noise, cause erratic readings, or in worst-case scenarios, short high voltage to ground through your low-voltage electronics. A 2-prong adapter is "floating," which isolates the meter from Earth ground.

### 2. Battery Power (9V)

You can power the Arduino Nano via the `VIN` and `GND` pins using a 9V battery.

* **Pros:** Complete electrical isolation (100% safe from ground loops), portable, zero mains noise.
* **Cons:** The Arduino, Display, and ADC consume current constantly. A standard 9V battery may drain relatively quickly.

### 3. ⚠️ WARNING: Computer USB Port

**DO NOT** power the BiasPro from your computer's USB port while it is connected to an amplifier.

* **The Danger:** Desktop computers (and many laptops) are grounded. Connecting the USB cable ties the Arduino's Ground to the Computer's Earth Ground. Since the Probe's Ground is connected to the Amp's Ground, you create a direct Ground Loop.

* **Risk:** If a probe accident occurs or there is a voltage potential difference, high current could flow through the USB cable, destroying your computer's motherboard, the Arduino, or the amplifier.

#### When is Computer USB safe?

* **Uploads:** It is safe to connect to the computer to upload code **ONLY IF** the bias probes are **disconnected** from the amplifier.

* **Debugging:** You can use the Arduino IDE Serial Monitor (9600 baud) to confirm the firmware boots (it prints a `BiasPro Booting...` status message), but **ensure the probes are NOT connected to a live amplifier**. If you must debug a live circuit, you must use a **USB Isolator** to protect your equipment.

---

## Installation

1. **Library Dependencies:** Install the following via the Arduino IDE Library Manager:
   - `Adafruit GFX Library`
   - `Adafruit ST7735 and ST7789 Library`
   - `Adafruit BusIO`

2. **Hardware Setup:**
   - **ADS1115:** Connect via I2C (SDA -> A4, SCL -> A5).
   - **TFT Display:** Connect via SPI (Pins 8, 9, 10, 11, 13 defined in code).
   - **Buttons:** Connect to Digital Pins 5 (Left), 6 (Right), and 7 (Center/Select).

3. **Upload:** Flash the `BiasPro` firmware to your Arduino Nano.

---

## User Guide & Navigation

* **Left / Right Buttons:** Scroll through menus or adjust values.
* **Center Button (Short Click):** Select an item, confirm an edit, or advance to the next field.
* **Center Button (Long Hold):** Open the Tool Menu or return to the main screen.
* **Left Button (Long Hold / Hold LEFT):** On the Profile Manager screen, immediately return to the main Tube Select screen without selecting a profile.

### RAW SENSORS (Diagnostics Mode)
**"RAW SENSORS"** is a highly visible, dedicated diagnostics menu item located at the very end of the Tube Profile Selection carousel. It is accessed and exited using a standard short click of the center button. Selecting this profile enters a diagnostics mode that displays the raw telemetry data coming directly from the Analog-to-Digital Converter (ADC) before final mathematical conversions are applied.

* **Raw ADC Counts (e.g., `CATH: 5254`):** These are the unconverted digital integer values read directly from the ADS1115 chip. The chip measures the physical voltage and outputs a proportional number ranging from `-32768` to `+32767`.

* **Millivolts (e.g., `41.04mV`):** The system mathematically converts the raw integer count into actual millivolts (`mV`). 
   * For the **Cathode**, this millivolt reading translates directly into Milliamps (mA) due to the 1Ω shunt resistor. 
   * For the **Plate**, this millivolt reading is later multiplied by your calibrated Voltage Scale Factor to calculate the true High Voltage.

This screen is highly useful for troubleshooting probe connections, checking for ADC noise, or manually verifying the calibration math.

### Firmware Quirks (By Design)

**1. The "Invisible Spaces" in the Profile Editor**
When creating a new tube profile, the Name field holds exactly **6 characters**. If you type a short name like `6V6` (3 characters), you still have 3 invisible blank spaces remaining. 

* **The Quirk:** The system will not drop down to the "Max Watts" line until you clear all 6 slots.

* **The Solution:** Simply rapid-click the **Center** button 3 times to skip past the invisible empty spaces and move to the next line.

**2. Screen Grid Current (`Src`) is in Permille (/1000)**
To calculate True Plate Dissipation, the BiasPro subtracts the Screen Grid Current from the Cathode reading. Floating-point decimals (like 5.5%) crash the Arduino's memory limit. Therefore, the firmware uses **Permille (parts-per-thousand)**. 

* To enter a percentage, simply multiply it by 10.
* **5.5%** = enter `55` /1000
* **13.0%** = enter `130` /1000
* **4.0%** = enter `40` /1000

---

## 🧪 Safe Biasing Protocol

1. **Bench Setup:** Connect your amplifier to a speaker load or reactive load box. An Isolation Transformer and a Variac are highly recommended for stable wall-voltage readings.

2. **Probe Connection:** Ensure the amplifier is powered OFF. Remove the power tubes, insert the BiasPro probes into the amp sockets, and place the tubes into the top of the probes.

3. **Select Tube Profile:** Power on the BiasPro. Select the matching tube profile (e.g., `6L6GC`). Press Center to enter **Live Bias Mode**.

4. **Power the Amp:** Turn the amplifier ON. Wait for the tubes to warm up, then disengage standby. 

5. **Adjust Bias:** Watch the **%** and **Watts** readings. Adjust your amplifier's internal bias potentiometer until the hottest tube reaches your desired target:

   - **Cool (50% - 60%):** Maximum clean headroom, longest tube life.
   - **Warm (60% - 70%):** The "Golden Zone". Balanced harmonics and warmth.
   - **Hot (70%+):** **DANGER.** High compression, short tube life, risk of red-plating.

### Hardware Faults & Lockouts

* **HARDWARE FAULT: CHECK I2C:** The ADS1115 ADC has disconnected. The meter will permanently halt to prevent phantom voltage readings. Power cycle to reset.

* **VOLTAGE LOCKOUT:** If the probes detect a voltage spike above your configured safety limit (default 600V), the screen turns red and locks. You must wait for the voltage to drop at least 50V below the limit before the meter releases the lock. Do not attempt to bypass this.

---

## Tube Profile Manager Configuration Guide

The **Tube Profile Manager** is powerful because it allows you to customize how the meter calculates Bias for specific tube types.

### 1. Max Dissipation (Watts)
This determines the "Red Line" for your tube. The meter uses this value to calculate the **% Dissipation** displayed on the screen.

* **How to set:** Look up the "Max Plate Dissipation" in the tube's datasheet.

* **Examples (Typical Values):**
  - **EL34:** 25 Watts
  - **6L6GC:** 30 Watts
  - **6V6:** 12-14 Watts (Check your specific tube's datasheet; older types are lower).
  - **KT88 / 6550:** 35-42 Watts
* **Usage:** If you set this to 25W and measure 17.5W of dissipation, the meter will display **70%**.

### 2. Screen % Factor (Accuracy Tuning)
* **The Physics:** Standard bias probes measure **Cathode Current**, which is the sum of Plate Current + Screen Current. However, Bias should be calculated using only **Plate Current**.
* **The Solution:** The "Screen % Factor" subtracts a percentage of the total current to estimate the true Plate Current.
  - `True Plate Current = Measured Current - (Measured Current * ScreenFactor)`
* **Important (Permille Entry):** To calculate True Plate Dissipation, the BiasPro subtracts the Screen Grid Current from the Cathode reading. Floating-point decimals (like 5.5%) crash the Arduino's memory limit. Therefore, the firmware uses **Permille (parts-per-thousand)**. To enter a percentage, simply multiply it by 10.
* **Recommended Settings:**
  - **EL34:** ~13.0% -> Enter **130** (Pentodes draw more screen current).
  - **KT88 / 6550:** ~6.0% -> Enter **60** (High power beam tetrodes).
  - **6L6GC:** ~5.5% -> Enter **55** (Beam Tetrodes draw less).
  - **EL84:** ~5.0% -> Enter **50** (Miniature pentodes).
  - **6V6:** ~4.5% -> Enter **45**
  - **Raw Mode:** Set to **0** to see the raw total current without subtraction.

---

## Calibration Guide

The meter comes with **Default** calibration settings (Automatic), but for professional accuracy, we strongly recommend **Manual** calibration.

**How to Enter Calibration Mode:**
1. **From Profiles Manager:** While on the **Profiles** manager screen (accessible by holding the Center button from the main Tube Selection screen), press and hold the **Center Button** to enter Calibration Mode.
2. **Startup Shortcut:** Press and hold the **Left Button** immediately when powering on (during the splash screen) to jump straight into Calibration Mode.

### Calibration Field Ranges & Adjustments
To prevent entering invalid or dangerous values, the firmware enforces strict calibration bounds and adjustment steps:
* **Voltage Scale (on-screen: `Scale A` / `Scale B`):** Range is `5.00` to `20.00` (adjusted in steps of `0.05` via Left/Right).
* **Shunt Resistor (on-screen: `Shunt A` / `Shunt B`):** Range is `500mR` to `5000mR` (representing 0.50Ω to 5.00Ω, adjusted in steps of `10mR`). The software displays and stores this in milliohms (mR) to maintain high precision without the memory overhead of floating-point decimals.
* **Voltage Limit (on-screen: `Limit`):** Range is `300V` to `800V` (adjusted in steps of `5V`).

### Method 1: Default Calibration (Automatic)
When you first power on the device (or after a reset), it loads standard default values:
* **Voltage Scale:** Defaults to **10.00**. (Assumes standard 1MΩ/100Ω probe divider).
* **Shunt Resistor:** Defaults to **1.00**. (Assumes a perfect 1.00Ω resistor).

**Use Case:** This is "Plug and Play." It works reasonably well for standard probes, but real-world resistors often vary slightly. It is always good practice to check these settings against a multimeter anyway.

### Method 2: Manual Calibration (Precision)
For the highest accuracy, use this method to match the meter readings to a trusted Digital Multimeter (DMM).

#### A. Calibrating Voltage Scale
1. **Safety First:** Refer to your amplifier's schematic to find a safe test point for the B+ Voltage (Plate Voltage) that supplies Pin 3 of the power tubes.
2. **Connect:** With the amp powered off and drained, connect the Bias Probe to the socket.
3. **Measure:** Power on the amp. Use your DMM to measure the actual DC Voltage at the safe test point you identified.
4. **Adjust:** In the Calibration screen, step to the **"Scale A"** field (short-press Center to advance between fields).
5. **Match:** Use the Left/Right buttons to adjust the scale factor until the **"Live V"** on the screen matches the voltage shown on your DMM.
6. **Repeat** for Probe B.

> [!WARNING]
> **The over-voltage LOCKOUT alarm does _not_ run on the Calibration screen.** The automatic red-screen lockout is active **only in Live Bias mode**. During voltage-scale calibration the amp is energised and this screen shows a live "Live V" reading, but it will **not** trip the lockout if the amp faults high. Treat "Live V" as a readout only — **not** a safety alarm. Watch your DMM, keep the plate voltage within your amp's expected range, and if anything looks wrong, shut down at the amp. Once calibrated, do your actual biasing from **Live Bias mode**, where the lockout is active.

#### B. Calibrating Shunt Resistors (Bias Scout Probes)
If you are using commercial probes like the **Tube Depot Bias Scout**, they typically have three banana plugs: Red, Black, and White.
1. **Disconnect:** Remove the probes from the amplifier. The probe must be unplugged to measure resistance accurately.
2. **Identify Plugs:**
   - **Black:** Common (Ground)
   - **White:** Cathode (Current Measurement)
   - **Red:** Plate (Voltage Measurement) - *Do not use for this step.*
3. **Find DMM Lead Resistance (Critical for Accuracy):**
   - Turn your DMM to its lowest Resistance (Ω) setting.
   - Touch the Red and Black DMM probes firmly together.
   - Note the number (e.g., **0.1Ω**). This is your "Lead Resistance."
4. **Measure Probe:** Connect one DMM lead to the **Black** plug and the other to the **White** plug of the bias probe. Write down the total resistance (e.g., **1.2Ω**).
5. **Calculate True Resistance:** Subtract the Lead Resistance from the Total.
   - *Math:* `1.2Ω (Total) - 0.1Ω (Leads) = 1.1Ω (True Resistance)`
   - *Why?* For a ~1.0Ω resistor, a 0.1Ω error is huge (10%)! Not subtracting this will cause the BiasPro to calculate your current and wattage inaccurately, which could lead you to bias your amp dangerously hot.
6. **Convert to Milliohms (mR):** To preserve flash memory and avoid heavy floating-point math, the software uses milliohms (mR) for whole-number precision. Multiply your True Resistance by 1000.
   - *Math:* `1.1Ω × 1000 = 1100mR`
7. **Adjust:** In the Calibration screen, step to the **"Shunt A"** field and input your calculated milliohm value (e.g., **1100**).
8. **Repeat** for Probe B. *(Note: If your DMM reading fluctuates for a probe—for example, bouncing between 1.1Ω and 1.2Ω—you can split the difference and enter a median value like **1050** for maximum precision).*

#### C. Voltage Threshold Limiter
The **"Limit"** setting is a safety tripwire.
* **How it works:** If the probe detects a voltage higher than this setting (default 600V), the device immediately triggers a Red "DANGER" screen and locks the interface.
* **Setting it:** Set this value slightly higher than your amplifier's maximum plate voltage (e.g., if your amp runs at 450V, set the limit to 500V or 550V). This protects the meter and warns you if the amp is behaving abnormally.

#### D. Saving & Exiting
Your settings are written to EEPROM **automatically** — each time you press **Center** to advance to the next field, and again whenever you leave the screen. There is no separate "save" item to look for. To leave calibration:

* **Short-press Center** to step through the fields (Scale A → Scale B → Shunt A → Shunt B → Limit). Pressing **Center** on the last field (**Limit**) exits and returns you to the **Tube Profile Manager**.
* **Press and hold Center** at any point to jump straight back to the main **Tube Select** screen.

Either exit stores your latest values, so you can leave whichever way is convenient.

---

### 🛡️ DIY Safety Upgrade (Input Protection)
If you are building this on perfboard (instead of using the custom PCB), we strongly recommend adding input protection to save your Arduino in case of a catastrophic tube failure.
* **The Mod:** Connect a **5.1V Zener Diode** (e.g., 1N4733A) between the **ADC Input (White Wire)** and **Ground**.
* **Orientation:** The "Stripe" (Cathode) of the Zener diode must face the Signal wire; the other end goes to Ground.
* **Function:** If a tube shorts and sends high voltage down the probe line, the Zener diode will "clamp" the voltage to 5.1V, sacrificing itself to save the ADS1115 and Arduino.
*(Note: The custom PCB already includes these diodes).*

---

## 💬 Frequently Asked Questions (FAQ)

### 1. Is the BiasPro actually accurate down to four significant figures?

**Yes.** BiasPro v1.1.1 achieves and delivers this four-digit precision across all metrics (`0.1V` resolution for plate voltage and `0.1mA` for cathode current) through two key engineering upgrades:

* **High-Precision 16-Bit Telemetry:** Bypassing the stock 10-bit Arduino ADC in favor of an ADS1115 ADC managed directly via targeted I2C register commands allows for granular data capture down to a tiny `0.0078125 mV` per bit.

* **Empirical Software Calibration:** By taking measurements with a high-quality multimeter (such as a Fluke 115) and factoring out multimeter lead resistance, you can enter custom milliohm (mR) shunt values and scale factors directly into the on-board EEPROM menu. This process empirically matches the math engine to the unique physical tolerances of your probes.

### 2. Does the device monitor live tube drift?

**Yes, explicitly and dynamically.** The BiasPro is a continuous monitor designed for active bench analysis, rather than a device that merely captures a snapshot.

* **Thermal Drift Monitoring:** While running in **Live Bias** mode, the system continuously polls the ADC channels several times per second, maintaining steady readouts through flicker-free incremental redraws. This feature allows technicians to let the amplifier idle and track current drift over extended one-hour burn-in windows.

* **Active Safety Catching:** If a power tube encounters a severe failure such as thermal runaway or a structural grid short, the plate voltage or current will drift uncontrollably. BiasPro actively monitors this loop on every cycle and will instantly trip the red **VOLTAGE LOCKOUT** emergency screen to secure the workbench.

---

## Project Lineage & Acknowledgements
BiasPro is an independent clean-room rewrite of the earlier
ToneAlchemy BiasMeter project. The BiasPro firmware was re-architected
and rewritten without intentionally reusing source code from the earlier
implementations.

The broader project lineage includes:

- **ArduinoBiasMeter** by John Wagner
- **Dual Channel Arduino Bias Tester beta 14** by Kiel Lydestad
  (3DBeerGoggles)
- **ToneAlchemy BiasMeter**, which evolved from those earlier projects

The earlier projects were distributed under CC BY 4.0 and are acknowledged
here for their historical contribution to the development of the Arduino
tube-bias-meter concept.

## ⚖️ License
This project is released under the **MIT License**. See [LICENSE](LICENSE) for details.
Third-party libraries and components remain subject to their respective
licences.

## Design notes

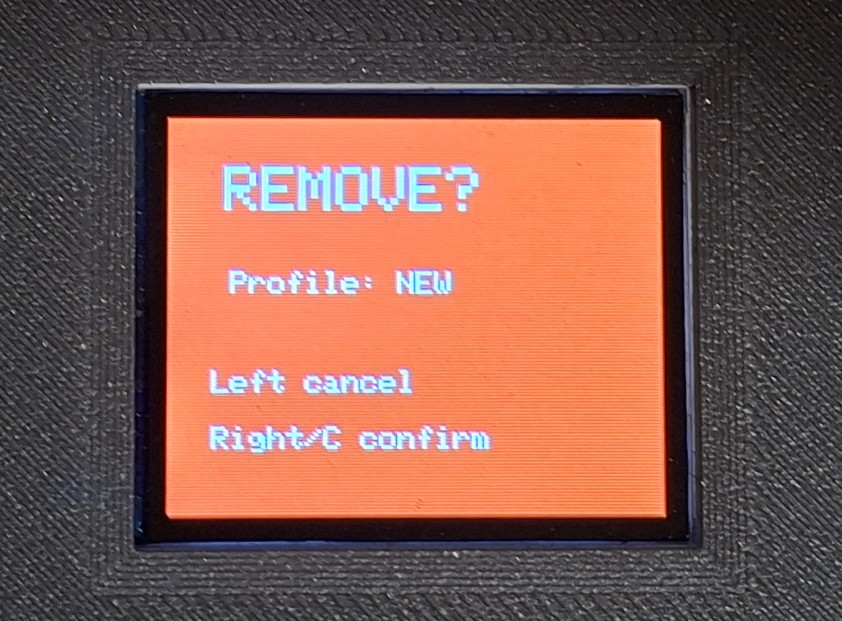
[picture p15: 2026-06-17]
IMAGES/REMOVE_PROFILE.jpg

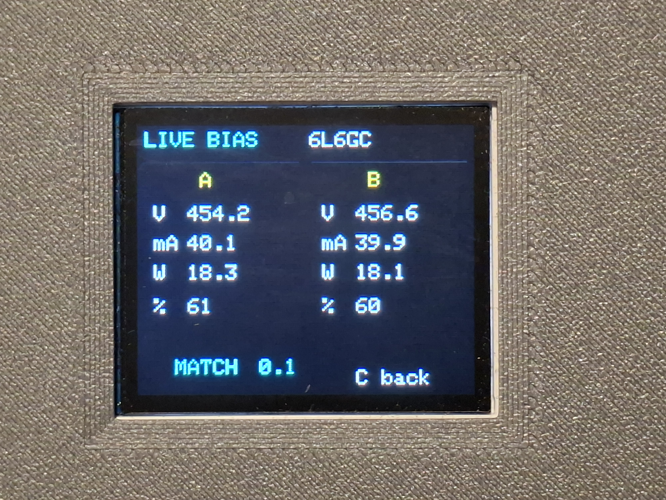
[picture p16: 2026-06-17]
IMAGES/Live_Bias_Mode.jpg

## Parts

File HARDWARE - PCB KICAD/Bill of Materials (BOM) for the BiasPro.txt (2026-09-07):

Bill of Materials (BOM) for the Arduino Tube Bias Meter
Project by Tone Alchemy - https://tonealchemy.com/biasmeter

=========================================================================
CORE ELECTRONICS
=========================================================================

[ ] 1x Arduino Nano (or compatible clone)
    - Link: https://amzn.to/4n7FcF8
 
[ ] 1x Adafruit ADS1115 16-Bit ADC
    - Link: https://amzn.to/46h8RpA

[ ] 2x 4.7kΩ (4,700 Ohm), 1% tolerance, 1/4W Metal Film Resistors (Recommended)
    - Purpose: ADS1115 SDA/SCL auxiliary I2C pull-ups for hardware EMI hardening in valve amp environments (see README.md)

[ ] 2x Tube Depot Bias Scout Probes (or equivalent custom-built probes)
    - Link: https://www.tubedepot.com/products/tubedepot-bias-scout-kit
    - Link Build manual: https://s3.amazonaws.com/tubedepot-com-production/spree/attached_files/td_bias_scout_assy_manual_v3.2.pdf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

=========================================================================
DISPLAY & INTERFACE
=========================================================================

[ ] 1x 1.8" 128x160 Color TFT Display (Adafruit PID 358 Breakout or compatible generic ST7735S module)
    - Link Adafruit PID 358: https://www.adafruit.com/product/358
    - Link AliExpress (Chinese clone): https://s.click.aliexpress.com/e/_c3E7gXid
    - Note: If using generic Chinese clone modules (e.g. ST7735S / NOMEN_TEC), 5x 1kΩ–1.5kΩ resistors are required in series on the TFT SPI/control lines (see README.md).

[ ] 3x Tactile Push Buttons (Normally Open, Panel Mount)
    - Link: https://amzn.to/3VZbeqO
    - Link: https://www.jaycar.com.au/metal-momentary-spst/p/SP0755

[ ] 1x Project Enclosure (e.g., Hammond 1590B or custom 3D printed case)
    - Link: https://www.tinkercad.com/things/52JVqAQGvP4/edit?sharecode=UnfbS9eHmJYUkZFwd_rKABnmDuH4jj8mL856R97Rt9c

=========================================================================
WIRING & CONNECTORS
=========================================================================

[ ] 1x USB to Type-C Data Cable with On/Off Switch (for programming and powering the Arduino)
    - Link:  https://s.click.aliexpress.com/e/_c4D2sYFh

[ ] Assorted Hook-up Wire (22 AWG solid core recommended)
    - Link: https://amzn.to/46MNg8q

[ ] 1x Stripboard or Perfboard (for mounting components)
    - Link: https://amzn.to/46eUWAf

=========================================================================
PROBE CONSTRUCTION (if building custom probes)
=========================================================================

[ ] 2x Octal Sockets (for tube connection)
    - Link:  https://www.amplifiedparts.com/products/socket-8-pin-octal-amphenol-style-1-532-mounting-hole 

[ ] 2x Octal Bases (to build the probe housing)
    - Link: https://s.click.aliexpress.com/e/_c3A4w85D
    - Link: https://www.amplifiedparts.com/products/tube-base-8-pin-octal-125-diameter

[ ] 2x 1MΩ (1,000,000 Ohm), 1% tolerance, 1/2W Metal Film Resistor
    - Link: https://s.click.aliexpress.com/e/_c4Bw7hpH

[ ] 2x 100Ω (100 Ohm), 1% tolerance, 1/8W Metal Film Resistor
    - Link: https://s.click.aliexpress.com/e/_c3nlLMiL

[ ] 2x 1Ω (1 Ohm), 1% tolerance, 1W Metal Oxide Resistor
    - Link: https://s.click.aliexpress.com/e/_c2zH3rlV

[ ] 6x 4mm Banana Plugs (2x Red, 2x Black, 2x White)
    - Link: https://s.click.aliexpress.com/e/_c3jXrt47

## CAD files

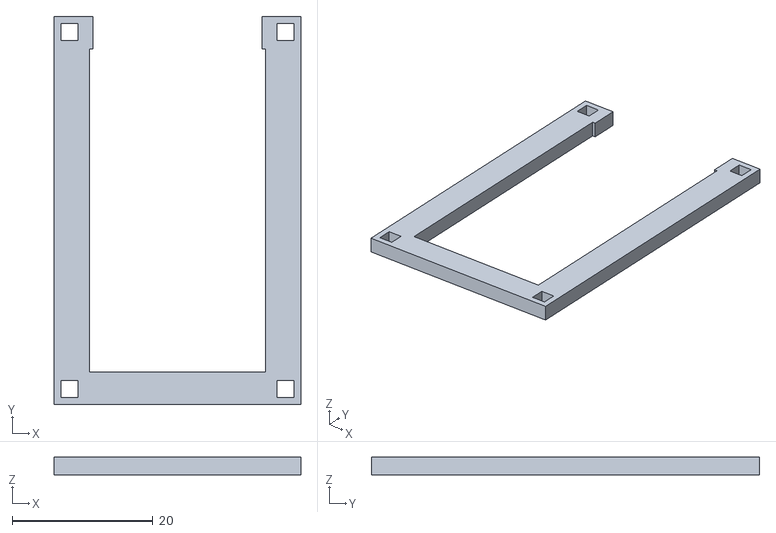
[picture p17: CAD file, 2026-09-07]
HARDWARE - PCB KICAD/BiasPro_Enclosure_STL/ST7735S_1.8TFT_Rear_Clamping_Bracket.stl
35.1 x 55.2 x 2.50

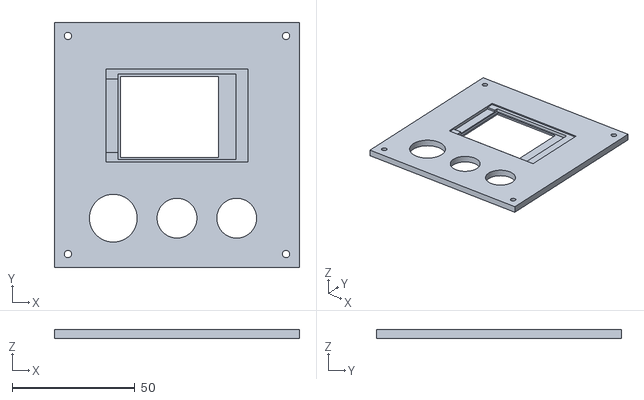
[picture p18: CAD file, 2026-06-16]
HARDWARE - PCB KICAD/BiasPro_Enclosure_STL/BiasPro_BOX_TOP.stl
100.0 x 100.0 x 3.50

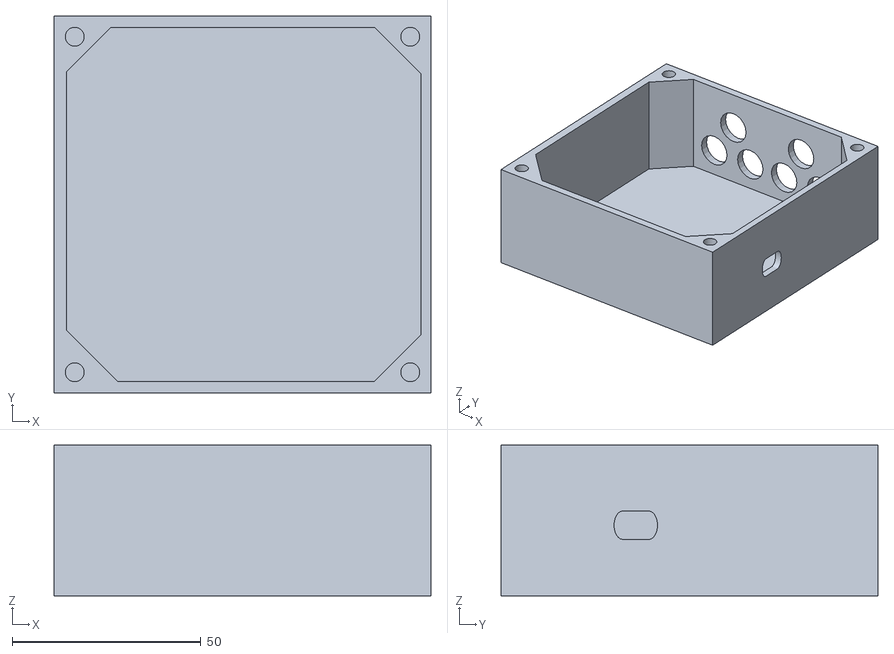
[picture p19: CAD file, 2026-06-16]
HARDWARE - PCB KICAD/BiasPro_Enclosure_STL/BiasPro_BOX_BOTTOM.stl
100.0 x 100.0 x 40.0

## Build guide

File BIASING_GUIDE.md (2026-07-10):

# 🎛️ Tube Amplifier Biasing Guide
**Focus Bias Example: Fender Prosonic & Fixed-Bias Class AB Amps**

This guide outlines the professional procedure for biasing high-gain tube amplifiers using the **Bias Meter**. While written with the **Fender Prosonic** in mind, these principles apply to most fixed-bias amplifiers (e.g., Marshall, Peavey, Soldano).

> [!WARNING]
> **SAFETY FIRST:** Biasing requires the amplifier to be **powered on** and running with lethal high voltage present. If you are not comfortable working with live high voltage, take your amp to a qualified technician.

## 🛠️ Recommended Test Bench Setup
For the most accurate and safe results, arrange your equipment in this specific order:

1.  **Isolation Transformer:** (Wall Outlet → Transformer). Isolates the test gear from Earth Ground for safety.
2.  **Variac:** (Transformer → Variac). Allows you to set the input voltage exactly to your country's standard (e.g., 240V, 120V). This prevents wall voltage drift from skewing your bias readings.
3.  **Dim Bulb Limiter:** (Variac → Limiter → Amp).
    * **CRITICAL:** Set the limiter to **BYPASS** mode (or use only the built-in voltmeter/ammeter). Do *not* bias through the bulb, or voltage sag will give false readings.
4.  **Load Box / Speaker:** The amp **MUST** have a speaker load connected. A reactive load box is recommended for silence.

## 🎚️ Amp Settings (Before Powering On)
To ensure a stable "Idle" reading, the signal path must be silent.

* **Input:** **Unplug everything.** (Most Fender amps short the input to ground when unplugged, ensuring zero noise).
    * *Alternative:* If you must leave a cable in, connect it to a guitar with the volume turned to **0**. Never leave a cable dangling (it acts as an antenna for hum).
* **Volume / Gain:** Set all to **0**.
* **Master Volume:** Set to **0**.
* **EQ (Treble/Mid/Bass):** Setting does not matter (signal is effectively zero), but 12 o'clock is standard.
* **Reverb:** Set to **0**.

## ⚡ The "Prosonic Protocol" (Rectifier Switching)
The Fender Prosonic (and Mesa Rectifiers) allows you to switch between Solid State (SS) and Tube Rectification. This changes the Plate Voltage and Bias requirements significantly.

**Rule:** Always Calibrate and Bias in **Solid State Mode** (Position 3).

### Why?
1.  **Manufacturer Spec:** The Prosonic Service Manual explicitly states: *"Bias set to ... Rectifier switch position 3."*
2.  **Voltage Stability:** The SS Rectifier provides the stiffest, highest voltage (~465V). The Tube Rectifier sags significantly (~440V). Biasing at the highest voltage ensures safety across all modes.
3.  **Bias Shift:** When you switch from SS (Class AB) to Tube (Class A/AB), the bias current naturally rises by approx 5-10%. You must set the SS mode conservatively to prevent the Tube mode from running dangerously hot.

---

## 📉 The "Safe Maximum" Strategy (6L6GC)
Since the bias rises when switching to Tube Mode, you should **not** bias the SS mode to the maximum (70%).

**The Math (6L6GC Tubes - 30W Max Dissipation):**
* **Target:** We want the *hottest* mode (Tube Rectifier) to land at **70%** (Max Safe).
* **Adjustment:** Since Tube Mode runs ~5% hotter, we set the **SS Mode to 65%**.

| Mode | Target Dissipation % | Target Wattage (per tube) | Result |
| :--- | :--- | :--- | :--- |
| **Solid State (Set Here)** | **60% - 65%** | **18W - 19.5W** | Clean, tight, punchy. |
| **Tube Rectifier (Check Only)** | **65% - 70%** | **19.5W - 21W** | Warm, compressed, spongy. |

### Step-by-Step Procedure
1.  **Connect:** Install Bias Probes into the amp sockets and install tubes into the probes. Connect probes to the Bias Meter.
2.  **Power Up:** Turn on the amp (in **SS Mode**) and let tubes warm up for at least 5 minutes.
3.  **Calibrate:**
    * **Find a Safe Test Point:** Use the amp's schematic to find the safest B+ voltage point that powers the tubes (e.g., the Standby Switch or the main B+ fuse).
    * **WARNING:** Avoid probing Pin 3 directly at the tube socket. A slip of the probe can short Pin 3 to Pin 2 (Heater) or Pin 4 (Screen), causing catastrophic damage. Always use a safer upstream point for measurement.
    * Measure this voltage with a trusted DMM.
    * Enter **Calibration Mode** on the BiasPro (hold the Center button from the main screen to enter the Profiles screen, then hold Center again).
    * Adjust `Volt Scale` until the BiasPro's "Live V" readout matches your DMM (e.g., 465V).
4.  **Set Bias:**
    * Watch the **Watts** reading on the Bias Meter.
    * Adjust the bias pot on the amp until the meter reads approximately **19 Watts** (63%).
5.  **Verify:**
    * Flip the switch to **Tube Rectifier Mode** (Position 2).
    * Observe the readings. The Watts should rise slightly (e.g., to 21W).
    * As long as the hottest mode stays near or below **21W (70%)**, you are perfectly biased. 

---

## 📊 Reference: Dissipation Targets
Use these generic targets for Class AB fixed-bias amps if you are not using the "Safe Maximum" strategy above.

* **Cool (50-60%):** Longest tube life, maximum clean headroom, potentially sterile sound.
* **Warm (60-70%):** The "Golden Zone." Good balance of warmth, harmonic content, and tube life.

* **Hot (70%+):** Reduced tube life. High compression and earlier breakup. **Risk of Red Plating.**

---
## 📚 References
* **Fender Prosonic Service Manual (Rev E, 1996):**
    * *Schematic Reference:* 050173
    * *Part Number:* 021-1007-000 (Combo) / 021-2007-000 (Head)
    * *Relevant Section:* Page 7, Schematic Diagram (Note 3: "Bias set to -46 VDC...")

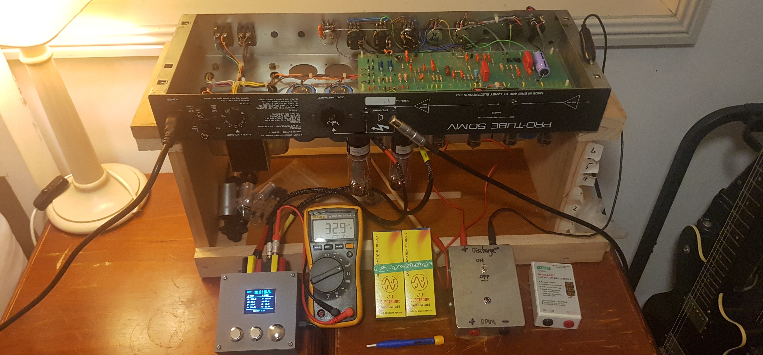
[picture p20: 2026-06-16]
IMAGES/BiasMeter_Setup_2.jpg

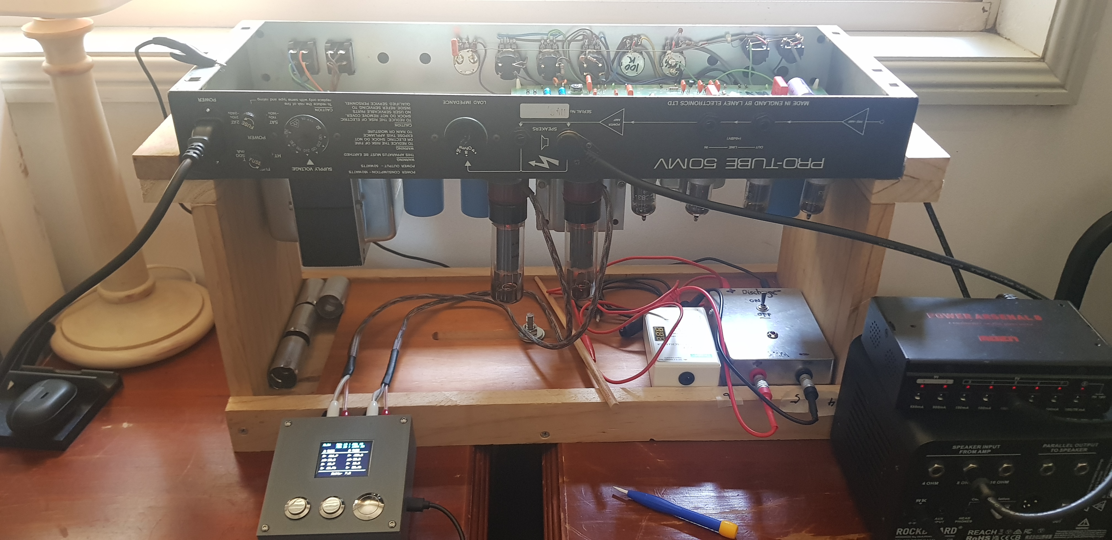
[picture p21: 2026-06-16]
IMAGES/BiasMeter_Setup_1.jpg

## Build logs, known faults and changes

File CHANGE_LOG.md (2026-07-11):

# BiasPro Public Changelog

All notable user-facing changes to the BiasPro firmware are documented in this file.

## [1.1.1] - 2026-07-11

### Added & Improved
- **Enhanced UI Layout:** Redesigned the "Tube Select" and "Profile Manager" screens to feature a vertically stacked and horizontally centered layout, making tube labels and specifications much easier to read.

- **Quick Escape Shortcut:** Added a new "Hold LEFT" hardware shortcut (with a visual on-screen footer) to quickly exit the Profile Manager and return directly to the main menu without needing to scroll.

- **Verified Stability:** Passed comprehensive mathematical and safety host-testing to guarantee the accuracy of bias calculations, EEPROM data integrity, and over-voltage lockouts.

## [1.1.0] - 2026-07-08

### Added
- **Live Calibration Voltage:** Added a real-time plate-voltage (Live V) readout on the Calibration screen. While adjusting the Scale or Shunt fields, users can now match the BiasPro directly against a digital multimeter (DMM) without leaving the screen.

## [1.0.0] - 2026-07-08

### Initial Release Highlights
First public release of the BiasPro firmware: a from-scratch, memory-safe, and highly robust rewrite for the dual-probe vacuum-tube bias meter. 

- **Dual-Probe Live Bias:** Real-time measurement of plate voltage, cathode current, and true plate dissipation (watts and percentage) with screen-current correction.
- **Tube Profile Manager:** Create, edit, and delete up to 10 tube profiles stored safely in EEPROM. Pre-loaded with 6 industry defaults (6L6GC, EL34, 6V6, EL84, KT88, 6550).
- **On-Board Calibration:** Calibrate voltage scales, shunt resistance, and over-voltage limits directly on the device—no source code edits required.
- **Advanced Safety Systems:** Features an active over-voltage lockout (with a 50V release hysteresis), boot-up hardware fault detection for the ADC/I2C bus, and software freeze protection to automatically recover from electrical interference.
- **Diagnostic Tools:** Includes a "RAW SENSORS" mode to view direct ADC counts and millivolts for advanced troubleshooting.
- **Data Protection:** Robust EEPROM storage with signature, range, and checksum validation that automatically restores safe defaults if data corruption is detected.

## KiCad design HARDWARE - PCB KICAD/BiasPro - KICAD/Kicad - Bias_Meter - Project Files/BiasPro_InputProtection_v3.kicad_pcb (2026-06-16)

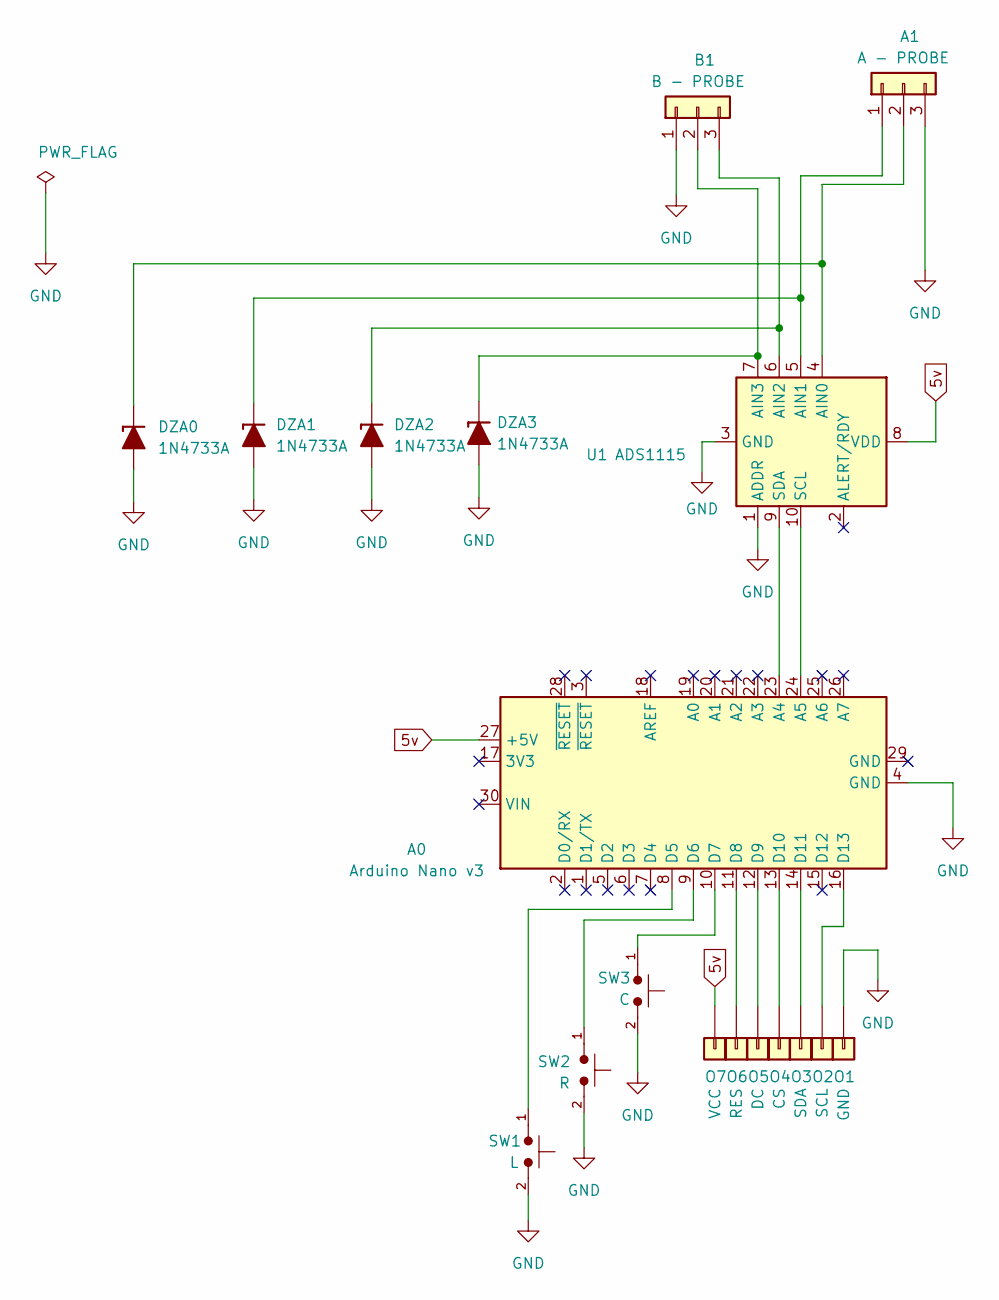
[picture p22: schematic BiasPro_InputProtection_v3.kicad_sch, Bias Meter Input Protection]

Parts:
A0: Arduino Nano v3; Arduino_Nano
A1: A - PROBE; PinHeader_1x3_P2.54_Drill1.1mm
B1: B - PROBE; PinHeader_1x3_P2.54_Drill1.1mm
DZA0, DZA1, DZA2, DZA3: 1N4733A; D_DO-41_SOD81_P10.16mm_Horizontal_Zener
O1: GND; TestPoint_THTPad_D2.0mm_Drill1.0mm
O2: SCL; TestPoint_THTPad_D2.0mm_Drill1.0mm
O3: SDA; TestPoint_THTPad_D2.0mm_Drill1.0mm
O4: CS; TestPoint_THTPad_D2.0mm_Drill1.0mm
O5: DC; TestPoint_THTPad_D2.0mm_Drill1.0mm
O6: RES; TestPoint_THTPad_D2.0mm_Drill1.0mm
O7: VCC; TestPoint_THTPad_D2.0mm_Drill1.0mm
SW1: L; PinHeader_1x2_P2.54mm
SW2: R; PinHeader_1x2_P2.54mm
SW3: C; PinHeader_1x2_P2.54mm
U1: ADS1115; Adafruit_ADS1115_NEW

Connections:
5v: A0.27 (+5V), O7.1, U1.8 (VDD)
GND: A0.4 (GND), A1.3, B1.1, DZA0.2 (A), DZA1.2 (A), DZA2.2 (A), DZA3.2 (A), O1.1, SW1.2, SW2.2, SW3.2, U1.1 (ADDR), U1.3 (GND)
unnamed: A0.23 (A4), U1.9 (SDA)
unnamed: A0.24 (A5), U1.10 (SCL)
unnamed: A0.8 (D5), SW1.1
unnamed: A0.9 (D6), SW2.1
unnamed: A0.10 (D7), SW3.1
unnamed: A0.11 (D8), O6.1
unnamed: A0.12 (D9), O5.1
unnamed: A0.13 (D10), O4.1
unnamed: A0.14 (D11), O3.1
unnamed: A0.16 (D13), O2.1
unnamed: A1.1, DZA1.1 (K), U1.5 (AIN1)
unnamed: A1.2, DZA0.1 (K), U1.4 (AIN0)
unnamed: B1.2, DZA3.1 (K), U1.7 (AIN3)
unnamed: B1.3, DZA2.1 (K), U1.6 (AIN2)

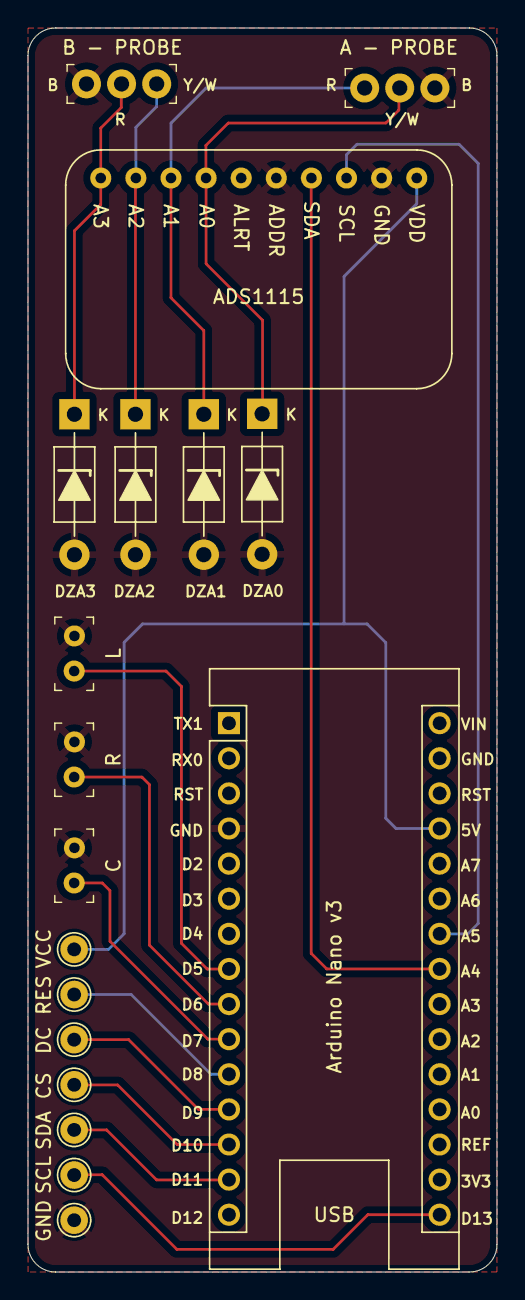
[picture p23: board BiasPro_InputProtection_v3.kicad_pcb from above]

Board: 2 copper layers, 33.9 x 90.0 mm, 18 parts (0 on the bottom side), 16 nets.

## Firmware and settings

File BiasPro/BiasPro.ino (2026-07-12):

/** Arduino Tube Amp BiasPro (v1.1.1)
 * Copyright (C) 2024-2026 - BiasPro by Charlie Isaac (ToneAlchemy.com)
 *
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
 * THE SOFTWARE IS PROVIDED "AS IS", WITHOUT WARRANTY OF ANY KIND, EXPRESS OR
 * IMPLIED, INCLUDING BUT NOT LIMITED TO THE WARRANTIES OF MERCHANTABILITY,
 * FITNESS FOR A PARTICULAR PURPOSE AND NONINFRINGEMENT. IN NO EVENT SHALL THE
 * AUTHORS OR COPYRIGHT HOLDERS BE LIABLE FOR ANY CLAIM, DAMAGES OR OTHER
 * LIABILITY, WHETHER IN AN ACTION OF CONTRACT, TORT OR OTHERWISE, ARISING FROM,
 * OUT OF OR IN CONNECTION WITH THE SOFTWARE OR THE USE OR OTHER DEALINGS IN THE
 * SOFTWARE.
 */

#include "ApplicationController.h"

ApplicationController app;

void setup() {
  Serial.begin(9600);
  Serial.println(F("BiasPro Booting..."));
  app.begin();
}

void loop() { app.tick(); }

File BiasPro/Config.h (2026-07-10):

#pragma once

// Arduino provides the fixed-width integer types via <Arduino.h> on the target;
// on a host build (e.g. the calculation tests) fall back to <cstdint> so this
// header - and everything that only needs the device constants/types - can be
// compiled without the Arduino toolchain.
#if defined(ARDUINO)
#include <Arduino.h>
#else
#include <stdint.h>  // host builds: fixed-width types in the global namespace
#endif

namespace DeviceConfig {
constexpr uint8_t TftSclkPin = 13;
constexpr uint8_t TftMosiPin = 11;
constexpr uint8_t TftCsPin = 10;
constexpr uint8_t TftDcPin = 9;
constexpr uint8_t TftResetPin = 8;

constexpr uint8_t ButtonCenterPin = 7;
constexpr uint8_t ButtonLeftPin = 5;
constexpr uint8_t ButtonRightPin = 6;

constexpr uint8_t AdsAddress = 0x48;
constexpr uint16_t EepromSignature = 12357;
constexpr uint8_t MaxTubeProfiles = 10;
constexpr uint8_t TubeNameLength = 7;
constexpr uint8_t SampleWindow = 20;

constexpr float AdsMillivoltsPerBit = 0.0078125f;
constexpr float SafetyResetMarginVolts = 50.0f;
} // namespace DeviceConfig

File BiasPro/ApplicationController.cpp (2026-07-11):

#include "ApplicationController.h"
#include "Config.h"
#include "MathCalculations.h"

namespace {
  constexpr uint32_t StartupScreenMillis = 1200UL;
  constexpr uint32_t LiveRefreshMillis = 220UL;
  constexpr uint32_t TelemetryRefreshMillis = 350UL;

  void clampSelection(uint8_t& selected, uint8_t count) {
    if (count == 0) {
      selected = 0;
    } else if (selected >= count) {
      selected = count - 1;
    }
  }

  void adjustCalibration(CalibrationSettings& settings, uint8_t field, ButtonEvent event) {
    const bool increase = event == ButtonEvent::Right;
    const bool decrease = event == ButtonEvent::Left;

    if (!increase && !decrease) {
      return;
    }

    const int8_t direction = increase ? 1 : -1;

    if (field == 0) {
      int16_t value = static_cast<int16_t>(settings.voltageScaleA_centi) + (direction * 5);
      if (value < 500) value = 500;
      if (value > 2000) value = 2000;
      settings.voltageScaleA_centi = static_cast<uint16_t>(value);
    } else if (field == 1) {
      int16_t value = static_cast<int16_t>(settings.voltageScaleB_centi) + (direction * 5);
      if (value < 500) value = 500;
      if (value > 2000) value = 2000;
      settings.voltageScaleB_centi = static_cast<uint16_t>(value);
    } else if (field == 2) {
      int16_t value = static_cast<int16_t>(settings.shuntA_milliohm) + (direction * 10);
      if (value < 500) value = 500;
      if (value > 5000) value = 5000;
      settings.shuntA_milliohm = static_cast<uint16_t>(value);
    } else if (field == 3) {
      int16_t value = static_cast<int16_t>(settings.shuntB_milliohm) + (direction * 10);
      if (value < 500) value = 500;
      if (value > 5000) value = 5000;
      settings.shuntB_milliohm = static_cast<uint16_t>(value);
    } else {
      int16_t value = static_cast<int16_t>(settings.voltageLimit) + (direction * 5);
      if (value < 300) value = 300;
      if (value > 800) value = 800;
      settings.voltageLimit = static_cast<uint16_t>(value);
    }
  }
}

void ApplicationController::begin() {
  display_.begin();
  display_.showStartup();

  storage_.beginWithDefaultsIfNeeded();
  calibration_ = storage_.loadCalibration();
  profileCount_ = storage_.loadProfiles(profiles_, DeviceConfig::MaxTubeProfiles);
  clampSelection(selectedProfile_, profileCount_);

  hardwareReady_ = hardware_.begin();
  protection_.begin();

  activeScreen_ = ScreenId::TubeSelect;
  startupUntilMillis_ = millis() + StartupScreenMillis;
  lastRefreshMillis_ = 0;
  screenNeedsPaint_ = true;
}

void ApplicationController::tick() {
  protection_.serviceWatchdog();

  const uint32_t now = millis();
  

  if (startupUntilMillis_ != 0 && static_cast<int32_t>(now - startupUntilMillis_) < 0) {
    return;
  }

  if (startupUntilMillis_ != 0) {
    startupUntilMillis_ = 0;
    screenNeedsPaint_ = true;

    // Jump to calibration if Left button is held during startup
    if (digitalRead(DeviceConfig::ButtonLeftPin) == LOW) {
      activeScreen_ = ScreenId::Calibration;
      calibrationField_ = 0;
      calibrationDirty_ = false;
      return;
    }
  }

  if (!hardwareReady_) {
    if (screenNeedsPaint_) {
      display_.drawHardwareFault();
      screenNeedsPaint_ = false;
    }
    return;
  }

  const ButtonEvent event = hardware_.readButtonEvent();

  if (activeScreen_ == ScreenId::TubeSelect) {
    if (event == ButtonEvent::Left) {
      selectedProfile_ = selectedProfile_ == 0 ? profileCount_ : selectedProfile_ - 1;
      if (screenNeedsPaint_) {
        display_.drawTubeSelection(profiles_, profileCount_, selectedProfile_);
        screenNeedsPaint_ = false;
      } else {
        display_.updateTubeSelection(profiles_, profileCount_, selectedProfile_);
      }
    } else if (event == ButtonEvent::Right) {
      selectedProfile_ = selectedProfile_ + 1;
      if (selectedProfile_ > profileCount_) selectedProfile_ = 0;
      if (screenNeedsPaint_) {
        display_.drawTubeSelection(profiles_, profileCount_, selectedProfile_);
        screenNeedsPaint_ = false;
      } else {
        display_.updateTubeSelection(profiles_, profileCount_, selectedProfile_);
      }
    } else if (event == ButtonEvent::Center) {
      if (selectedProfile_ == profileCount_) {
        activeScreen_ = ScreenId::SensorTelemetry;
      } else {
        activeScreen_ = ScreenId::LiveBias;
      }
      screenNeedsPaint_ = true;
      lastRefreshMillis_ = 0;
      return;
    } else if (event == ButtonEvent::LongCenter) {
      if (selectedProfile_ < profileCount_) {
        activeScreen_ = ScreenId::ProfileManager;
        screenNeedsPaint_ = true;
        return;
      }
    }

    if (screenNeedsPaint_) {
      display_.drawTubeSelection(profiles_, profileCount_, selectedProfile_);
      screenNeedsPaint_ = false;
    }

    return;
  }

  if (activeScreen_ == ScreenId::LiveBias) {
    if (event == ButtonEvent::Center) {
      activeScreen_ = ScreenId::TubeSelect;
      screenNeedsPaint_ = true;
      return;
    }

    if ((now - lastRefreshMillis_ >= LiveRefreshMillis || screenNeedsPaint_) && profileCount_ > 0) {
      if (screenNeedsPaint_) {
        display_.drawLiveBiasFrame(profiles_[selectedProfile_]);
      }

      RawAdcFrame raw = hardware_.readAdcFrame(DeviceConfig::SampleWindow);

      if (raw.valid) {
        BiasReading reading = MathCalculations::computeBias(
          raw,
          calibration_,
          profiles_[selectedProfile_]
        );

        if (protection_.shouldEnterLockout(reading, calibration_)) {
          activeScreen_ = ScreenId::FaultLockout;
          display_.drawVoltageLockoutFrame(calibration_.voltageLimit);
          display_.updateVoltageLockoutValues(reading.voltsA, reading.voltsB);
          lastRefreshMillis_ = now;
          screenNeedsPaint_ = false;
          return;
        }

        display_.updateLiveBiasValues(reading);
      }
      // Invalid frame (I2C fault): freeze the last good values rather than
      // rendering a misleading 0.0 V / 0 mA reading.

      lastRefreshMillis_ = now;
      screenNeedsPaint_ = false;
    }

    return;
  }

  if (activeScreen_ == ScreenId::FaultLockout) {
    if (event == ButtonEvent::LongCenter) {
      activeScreen_ = ScreenId::SensorTelemetry;
      screenNeedsPaint_ = true;
      lastRefreshMillis_ = 0;
      return;
    }

    if (now - lastRefreshMillis_ >= LiveRefreshMillis && profileCount_ > 0) {
      if (screenNeedsPaint_) {
        display_.drawVoltageLockoutFrame(calibration_.voltageLimit);
        screenNeedsPaint_ = false;
      }

      RawAdcFrame raw = hardware_.readAdcFrame(DeviceConfig::SampleWindow);

      if (raw.valid) {
        BiasReading reading = MathCalculations::computeBias(
          raw,
          calibration_,
          profiles_[selectedProfile_]
        );
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

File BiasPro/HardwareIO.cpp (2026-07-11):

#include "HardwareIO.h"
#include "Config.h"
#include "MathCalculations.h"
#include <Wire.h>


bool HardwareIO::begin() {
  pinMode(DeviceConfig::ButtonCenterPin, INPUT_PULLUP);
  pinMode(DeviceConfig::ButtonLeftPin, INPUT_PULLUP);
  pinMode(DeviceConfig::ButtonRightPin, INPUT_PULLUP);

  Wire.begin();
#if defined(WIRE_HAS_TIMEOUT)
  Wire.setWireTimeout(25000, true);
#endif
  Wire.beginTransmission(DeviceConfig::AdsAddress);
  if (Wire.endTransmission() != 0) {
    return false;
  }

  return true;
}

ButtonEvent HardwareIO::readButtonEvent() {
  if (pendingEvent_ != ButtonEvent::None) {
    ButtonEvent e = pendingEvent_;
    pendingEvent_ = ButtonEvent::None;
    return e;
  }

  const uint32_t now = millis();
  constexpr uint32_t DebounceMillis = 25UL;
  constexpr uint32_t RepeatGuardMillis = 60UL;
  constexpr uint32_t LongPressMillis = 900UL;
  constexpr uint8_t LeftMask = 0x01;
  constexpr uint8_t RightMask = 0x02;
  constexpr uint8_t CenterMask = 0x04;

  uint8_t rawMask = 0;
  if (digitalRead(DeviceConfig::ButtonLeftPin) == LOW) rawMask |= LeftMask;
  if (digitalRead(DeviceConfig::ButtonRightPin) == LOW) rawMask |= RightMask;
  if (digitalRead(DeviceConfig::ButtonCenterPin) == LOW) rawMask |= CenterMask;

  if (rawMask != lastRawMask_) {
    lastRawMask_ = rawMask;
    lastRawChangeMillis_ = now;
    return ButtonEvent::None;
  }

  if (now - lastRawChangeMillis_ < DebounceMillis) {
    return ButtonEvent::None;
  }

  if (rawMask != stableMask_) {
    stableMask_ = rawMask;

    if (stableMask_ != 0 && !pressActive_) {
      pressActive_ = true;
      longCenterSent_ = false;
      holdLeftSent_ = false;
      pressedMask_ = stableMask_;
      pressStartMillis_ = now;
      return ButtonEvent::None;
    }

    if (stableMask_ == 0 && pressActive_) {
      pressActive_ = false;

      uint32_t guardMillis = ((pressedMask_ & CenterMask) != 0) ? 250UL : RepeatGuardMillis;

      if (now - lastButtonMillis_ < guardMillis || longCenterSent_ || holdLeftSent_) {
        return ButtonEvent::None;
      }

      lastButtonMillis_ = now;

      if ((pressedMask_ & CenterMask) != 0) return ButtonEvent::Center;
      if (pressedMask_ == LeftMask) return ButtonEvent::Left;
      if (pressedMask_ == RightMask) return ButtonEvent::Right;
    }

    return ButtonEvent::None;
  }

  if (
    pressActive_ &&
    !longCenterSent_ &&
    (stableMask_ & CenterMask) != 0 &&
    now - pressStartMillis_ >= LongPressMillis
  ) {
    longCenterSent_ = true;
    lastButtonMillis_ = now;
    return ButtonEvent::LongCenter;
  }

  if (
    pressActive_ &&
    !holdLeftSent_ &&
    (stableMask_ & LeftMask) != 0 &&
    now - pressStartMillis_ >= LongPressMillis
  ) {
    holdLeftSent_ = true;
    lastButtonMillis_ = now;
    return ButtonEvent::HoldLeft;
  }

  return ButtonEvent::None;
}

RawAdcFrame HardwareIO::readAdcFrame(uint8_t samples) {
  if (samples == 0) {
    samples = 1;
  }

  int32_t cathodeATotal = 0;
  int32_t plateATotal = 0;
  int32_t cathodeBTotal = 0;
  int32_t plateBTotal = 0;
  bool frameValid = true;

  for (uint8_t index = 0; index < samples; ++index) {
    for (uint16_t i = 0; i < 4; ++i) {
      uint16_t config = 0x8000 | ((4 + i) << 12) | 0x0A00 | 0x0100 | 0x00E3;

      Wire.beginTransmission(DeviceConfig::AdsAddress);
      Wire.write(0x01);
      Wire.write((uint8_t)(config >> 8));
      Wire.write((uint8_t)(config & 0xFF));
      if (Wire.endTransmission() != 0) {
        frameValid = false;
      }

      delay(2);

      ButtonEvent e = readButtonEvent();
      if (e != ButtonEvent::None && pendingEvent_ == ButtonEvent::None) {
        pendingEvent_ = e;
      }

      Wire.beginTransmission(DeviceConfig::AdsAddress);
      Wire.write(0x00);
      if (Wire.endTransmission() != 0) {
        frameValid = false;
      }
      Wire.requestFrom((uint8_t)DeviceConfig::AdsAddress, (uint8_t)2);

      int16_t val = 0;
      if (Wire.available() == 2) {
          const uint8_t hi = Wire.read();
          const uint8_t lo = Wire.read();
          val = static_cast<int16_t>((static_cast<uint16_t>(hi) << 8) | lo);
      } else {
          frameValid = false;
      }

      if (i == 0) cathodeATotal += val;
      else if (i == 1) plateATotal += val;
      else if (i == 2) cathodeBTotal += val;
      else if (i == 3) plateBTotal += val;
    }
  }

  RawAdcFrame frame;
  frame.cathodeA = static_cast<int16_t>(cathodeATotal / samples);
  frame.plateA = static_cast<int16_t>(plateATotal / samples);
  frame.cathodeB = static_cast<int16_t>(cathodeBTotal / samples);
  frame.plateB = static_cast<int16_t>(plateBTotal / samples);
  frame.valid = frameValid;
  return frame;
}
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

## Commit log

2026-06-16 added new files and readme update.
    [BIASMETER_BOX_BOTTOM.stl, BIASMETER_BOX_TOP.stl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]
2026-07-11 update README.md for Calibrating Shunt A and B Probes.
2026-07-21 Update Bill of Materials (BOM) for the BiasPro.txt
2026-09-07 updated readme and bom
